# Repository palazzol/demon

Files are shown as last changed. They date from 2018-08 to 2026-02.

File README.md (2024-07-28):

# Demon Debugger system - 2.0 coming soon!

Debugger/Monitor for small "computers"

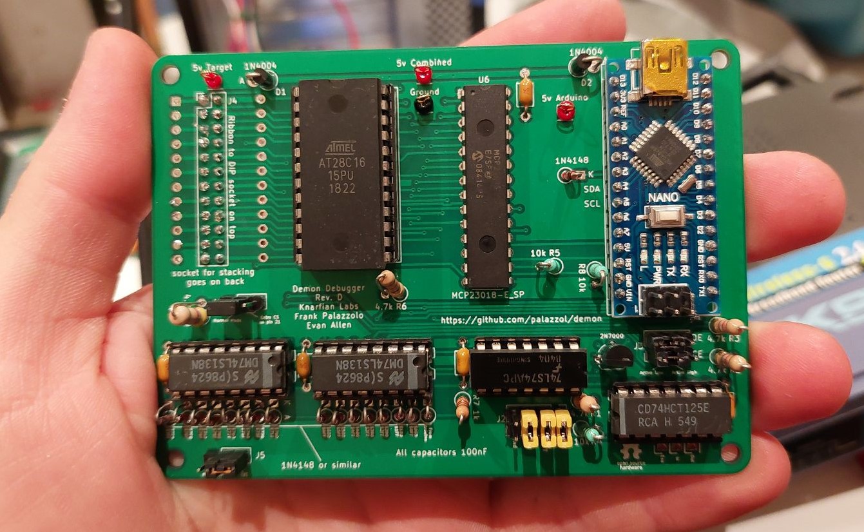
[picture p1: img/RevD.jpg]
RevD Photo


## Vintage Computer Festival Midwest 17 - 2022

- [YouTube](https://youtu.be/M9XML7viIT8)

- [Slides](doc/DD_Presentation-VCFMW_2022.pdf)

## Important Note

**We would like to port this to more systems, and/or help others fix their old things. Please let us know if you need any help getting this system going, should you choose to give it a try!**

## Newly added

* 68HC11 Reference Target - used for Chuck E Cheese Cyberamics computer

## New in version 2.0

* No EPROM programmer needed, reflash through USB serial
* New CPUs supported
  * 6800, 6809
* New targets supported
  * MicroProfessor-1 (Z80 trainer)
  * Heathkit ET-3400(A) (6800 trainer)
  * Heathkit ET-3404 (ET-3400(A) + 6809 adapter) (6809 trainer)
* GUI client
* Python API (alpha) for automating control of targets
* Modularized target code, less work for supporting new targets

## Description

Demon Debugger is a tool that can be used to repair and reverse-engineer devices with 8 and 16 bit CPUs, such as arcade machines, console games, embedded computers, single board computers, etc.  It provides a debugging console, and so is especially useful for systems that lack a working one.

It has been ported to Z80-based, 6502-based, 6800-based, 6809-based, and CP1610-based systems.  There are ports underway to other CPU architectures.

Unfortunately, Demon Debugger can't be used on a totally broken system.  The target system must have a working CPU, and at least a small amount of ROM and RAM.  However, we have found that for most hardware, it's really not too hard to get a system to this point.

## How it Works

In ROM I/O mode, The Demon Debugger board cable plugs into a socket on the target system, in place of a standard JEDEC ROM/EPROM chip.  Then, your PC can communicate with the target over serial, using a standard USB connection.

If your target system is already supported, there will be a target image already built, which you can upload onto your target.  

To support a totally new target system, a small amount of tweaking may need to be done to the assembly code for your target. Generally, if you know the memory map for your system, this is really easy to do.

## More Details

The Demon Debugger system has evolved over time.  If you have a Demon Debugger board, you can use ROM I/O mode with prebuilt target code, and get started right away, without any other tools.  If you need to support a new target, you can still use ROM I/O mode, once you build a new target code.

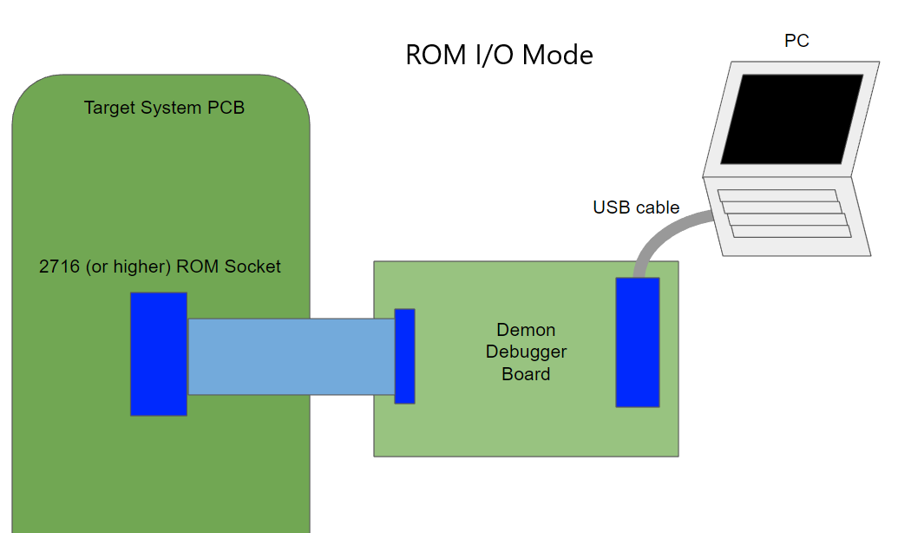
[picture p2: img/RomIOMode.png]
Rom I/O mode diagram


If you don't have a Demon Debugger board, you can still use the Demon Debugger system in Tethered mode, provided you have a few other capabilities.  It requires only an Arduino Nano/Uno, a single transistor, and the ability to program an EPROM chip.  You need to identify points on your target which can be used (2 outputs, 1 input, and a ground), wire up your modified Arduino accordingly, and modify the communication routines in the target to use those points.  There are a few examples in the repo of doing this.

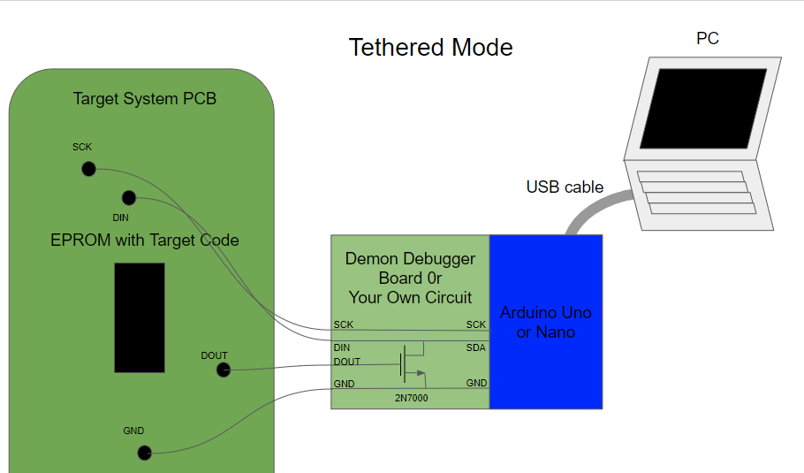
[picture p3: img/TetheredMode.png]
Tethered mode diagram


## Currently Supported Targets

### 6502

* Generic 6502 (Works on most targets) - Atari Asteroids, VCFMW Badge!
* Atari Asteroids Arcade, tethered mode
* Atari Starship 1 Arcade

### 6800

* Heathkit ET-3400(A) (6800 trainer)

### 6809

* Heathkit ET-3404 (ET-3400(A) + 6809 adapter) (6809 trainer)
* Radio Shack Color Computer - Cartridge (6809)

### 6811

* (Chuck E. Cheese Cyberamics Computer) (6811 reference)

### Z80

* Z80 reference code (Tweakable to work on most targets)
* Sega Star Trek Arcade
* Sega Star Trek Arcade, tethered mode
* Bally Midway Gorf Arcade 
* Bally Astrocade, cartridge
* Colecovision/Bit90, cartridge
* Universal Space Raider Arcade
* MicroProfessor-1 (Z80 trainer)

### CP1610

* Mattel Intellivision - via LTO Flash cartridge*

### Other - coming soon

* Mattel Intellivision, via T-Card cartridge (CP1610 target)
* 8080/8085 targets
* Atari 2600 (6502)
* RCA1802 targets
* OS816 SBC (65C816 target)
* TI 99/4A cartridge (TMS9900 target)

## Command Line Client

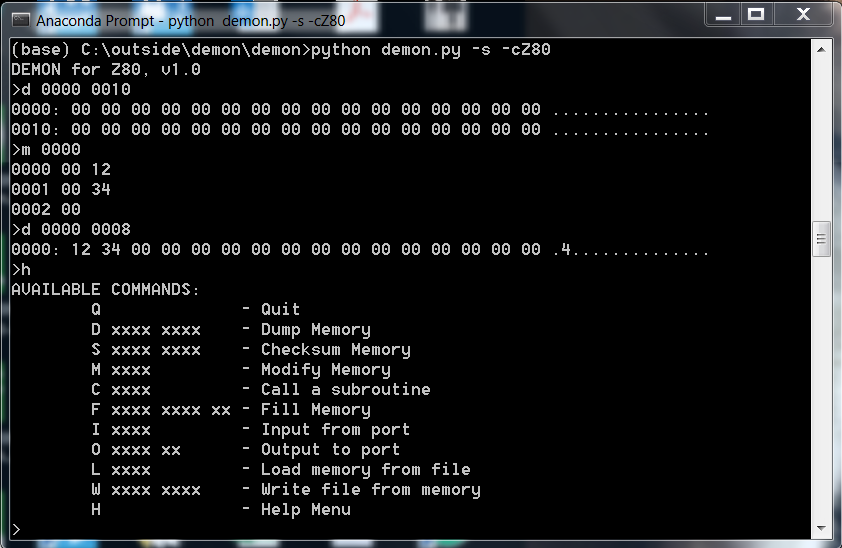
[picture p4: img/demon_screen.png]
Command Line Screenshot


## GUI Client (WIP)

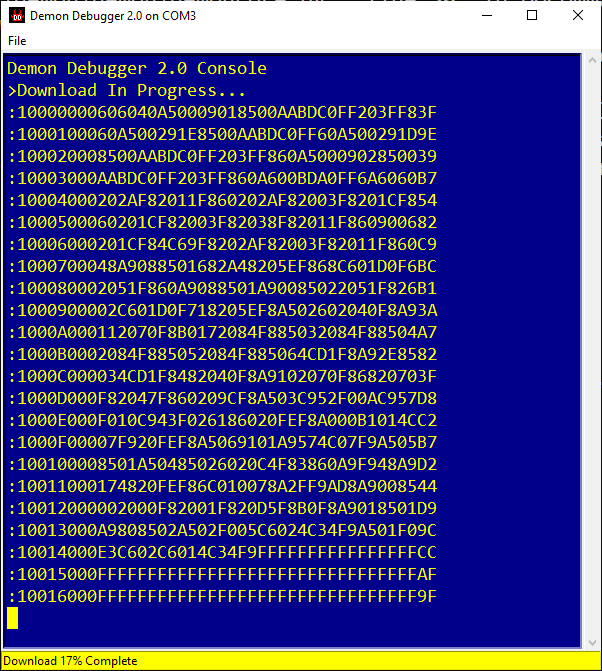
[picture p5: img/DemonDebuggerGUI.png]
GUI Screenshot


## API

For now, please see the file demonapi.py

## Old Videos

Tethered Mode - [Sega Sound Board test](https://www.youtube.com/watch?v=uYlbb8uPjoU) Quality is not very good, but the Arduino module is next to the laptop

[Intellivision Demo](https://www.youtube.com/watch?v=_8YfCMpHLhY) Better quality, no Arduino needed using native serialport on the LTO Flash cart.

## 3D Rendering from KiCad

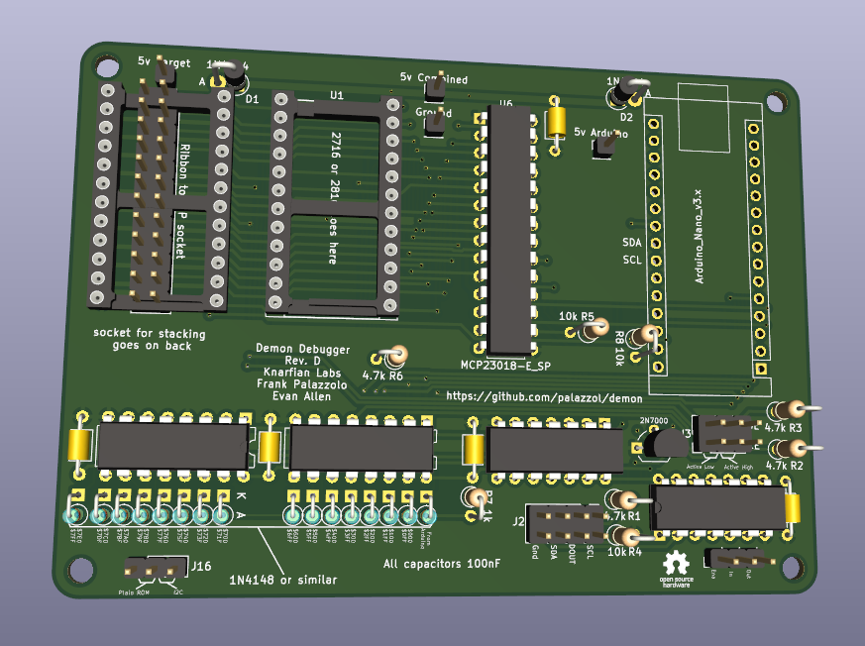
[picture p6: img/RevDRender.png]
Rev D Rendering


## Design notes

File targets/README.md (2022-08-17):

# Building firmware targets for Demon Debugger

Firstly, if you're really lucky, you might find your target code in the bin directory.

If not, head to the src directory

The code is split into subdirectories as follows:

    * core - assembly routines for all CPUs which define the core of Demon Debugger
    * io - assembly routines for interfacing to your target via romio, or tethered mode
    * templates - configuration files (with code snippets) defining how to build a rom image
    * targets - configuration files for each supported target
    * tools - tools needed to build the firmware, but especially ddmake, which does it all

Each target file references a single template file.  This helps a lot, because similar targets share a single template.

For example, if you have a 2K Z80 target (at 0x0000), or a 2K 6502 target (at 0xF800), all the work is done for you.
You will see template files for building either of these, and the z80ref and 6502ref targets use them.

There is also a template for building Z80 cartridge images, which currently works with the Astrocade and Colecovision.

Finally, there are examples of older targets/templates which use the tethered mode of communication.

To build an image, go into the targets directory (where the target .toml files are) and invoke the ddmake.py program with the target (basename) as an argument.  (You will need a python3 environment for now.)  ddmake scans the target and referenced template files, and builds an asm in the corresponding bin/<target>/<target>.asm.  Then, it invokes the assembler, linker, and output converter programs.  If all goes well, you will have:

    * <target>.asm - abbreviated assembly program
    * <target>.bin - binary image
    * <target>.hex - hex file suitable for automatic upload to the Demon Debugger hardware
    * <target>.rst - a nice, absolute listing file of the build image, generated by the linker

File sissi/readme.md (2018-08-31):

# Arduino USB/Serial to Pseudo-I2C Slave Adapter

The Arduino Uno adapter consists of an Arduino Uno,
and a single 2N7000 FET (Transistor)

The target device (cable) has four pins, SCL, DOUT, DIN, and GND
The 2N7000 has three pins, labelled Gate, Drain, and Source
The Arduino itself uses 3 pins, A5 (SCL), A4 (SDA), and GND

The wiring is as follows:

	TARGET      FET         ARDUINO
	--------------------------------
	SCL         N/C         A5 (SCL)
	DOUT        GATE        (N/C)
	DIN         DRAIN       A4 (SDA)
	GND         SOURCE      GND

This arrangement allows the target to provide pure inputs and outputs,
but interface directly to the I2C bus.

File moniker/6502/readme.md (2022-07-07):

## Old build targets
# moniker       - original Asteroids code for use with tethered system
# ref6502_old   - generic 6502 target (Asteroids) - works with Rev C boards
# starship1_old - starship one 6502 target - works with Rev C boards

## New build targets
# ref6502   - generic 6502 target (Asteroids) - works with Rev D boards
# starship1 - Starship One target - - works with Rev D boards

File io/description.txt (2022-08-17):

ROM-based I/O interface for Demon Debugger!

As the type of targets expand beyond Arcade PCBs, it becomes more
difficult to identify I/O pins to use for communication on the target.

Since we are generally replacing code with a EPROM containing the target code,
why not make an interface that looks like part of the EPROM space?

Here is the general idea:

1) Demon Debugger code easily fits into 512 bytes for all targets
2) A 2716-style 2K ROM interface is generic enough to be adapted for most targets
3) Sometimes we need code at the front of memory (ex. Z80 startup, NMI handler, etc.) and
   sometimes the end of memory (ex. 6502 reset vector)
4) So, we use a 2K memory space, but put a "hole" in the middle for I/O

Memory Map for I/O interface:

2K Total Memory Space:

0x000 - 0x79F:  "Front" ROM Space      - pass thru to our EPROM
0x7A0 - 0x7BF:  Special I/O READ area  - D0 reads from the Arduino
0x7C0 - 0x7DF:  Special I/O WRITE area - D1/D0 write to the Arduino
0x7E0 - 0x7ff:  "Back" ROM Space       - pass thru to our EPROM

I/O Reads are easy, skip the EPROM and just read from the Arduino pin

I/O Writes are a little trickier, we fill the EPROM region with D1/D0
matching A1/A0, and then we read from the eprom while writing to the Arduino
with D1/D0 at the same time.  To be clear, the CPU reads from the EPROM, 
but the data on the bus also gets written to the Arduino.

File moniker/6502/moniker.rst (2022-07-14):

                              1 ;
                              2 ; Moniker - 6502 Version
                              3 ; by Frank Palazzolo
                              4 ; For Atari Asteroids
                              5 ;
                              6 ; This code replaces ROM J2 on my Asteroids
                              7 ;
                              8 ; SCL  - WRITE 0x3200, bit0 (0x01) 2 player start lamp - active low only because led is wired to +5V
                              9 ; DOUT - WRITE 0x3200, bit1 (0x02) 1 player start lamp - active low only because led is wired to +5V
                             10 ; DIN  - READ  0x2405, bit7 (0x80) thrust button - inverted on input
                             11 
                             12         .area   CODE1   (ABS)   ; ASXXXX directive, absolute addressing
                             13 
                     2800    14 DIP7	.equ	0x2800	;bit0 = DIP switch 7
                     3200    15 LEDS	.equ	0x3200	;bit0 = 2 player start lamp
                             16 			;bit1 = 1 player start lamp
                             17 		
                     0000    18 LEDBUF	.equ	0x00	;buffer for lamps
                     0001    19 B	.equ	0x01	;general purpose
                     0002    20 C	.equ	0x02	;general purpose
                     0003    21 CMDBUF0 .equ	0x03	;command buffer
                     0004    22 CMDBUF1 .equ	0x04	;command buffer
                     0005    23 CMDBUF2 .equ	0x05	;command buffer
                     0006    24 CMDBUF3 .equ	0x06	;command buffer
                             25 
                     00FE    26 SSTACK	.equ	0xfe	;start of stack
                             27 
                     0011    28 I2CRADR .equ     0x11    ;I2C read address  - I2C address 0x08
                     0010    29 I2CWADR .equ     0x10    ;I2C write address - I2C address 0x08
                             30 
                     0180    31 BIGDEL	.equ	0x0180
                             32 
   7800                      33 	.org	0x7800	;start of rom at j2
                             34 	
   7800 40            [ 6]   35 NMI:	rti
                             36 
   7801 A5 00         [ 3]   37 SETSCL:	lda	LEDBUF
   7803 09 01         [ 2]   38 	ora	#0x01
   7805 85 00         [ 3]   39 	sta	LEDBUF
   7807 8D 00 32      [ 4]   40 	sta	LEDS
   780A 20 37 78      [ 6]   41 	jsr	I2CDLY
   780D 60            [ 6]   42 	rts
                             43 
   780E A5 00         [ 3]   44 CLRSCL:	lda	LEDBUF
   7810 29 FE         [ 2]   45 	and	#0xfe
   7812 85 00         [ 3]   46 	sta	LEDBUF
   7814 8D 00 32      [ 4]   47 	sta	LEDS
   7817 60            [ 6]   48 	rts
                             49 	
   7818 A5 00         [ 3]   50 SETSDA:	lda	LEDBUF
   781A 29 FD         [ 2]   51 	and	#0xfd
   781C 85 00         [ 3]   52 	sta	LEDBUF
   781E 8D 00 32      [ 4]   53 	sta	LEDS
   7821 20 37 78      [ 6]   54 	jsr	I2CDLY
   7824 60            [ 6]   55 	rts
                             56 
   7825 A5 00         [ 3]   57 CLRSDA:	lda	LEDBUF
   7827 09 02         [ 2]   58 	ora	#0x02
   7829 85 00         [ 3]   59 	sta	LEDBUF
   782B 8D 00 32      [ 4]   60 	sta	LEDS
   782E 20 37 78      [ 6]   61 	jsr	I2CDLY
   7831 60            [ 6]   62 	rts
                             63 
   7832                      64 READSDA:        
   7832 AD 00 28      [ 4]   65         lda	DIP7
   7835 6A            [ 2]   66 	ror			
   7836 60            [ 6]   67 	rts				
                             68 
                             69 ; Delay for half a bit time
   7837 60            [ 6]   70 I2CDLY:	rts		; TBD - this is plenty?
                             71 
                             72 ; I2C Start Condition
   7838                      73 I2CSTART:
   7838 20 25 78      [ 6]   74         jsr    CLRSDA      
   783B 20 0E 78      [ 6]   75         jsr    CLRSCL
   783E 60            [ 6]   76         rts
                             77 
                             78 ; I2C Stop Condition
                             79 ; Uses HL
                             80 ; Destroys A
   783F                      81 I2CSTOP:
   783F 20 25 78      [ 6]   82         jsr    CLRSDA
   7842 20 01 78      [ 6]   83         jsr    SETSCL
   7845 20 18 78      [ 6]   84         jsr    SETSDA
   7848 60            [ 6]   85         rts
                             86         
   7849                      87 I2CRBIT:
   7849 20 18 78      [ 6]   88 	jsr	SETSDA
   784C 20 01 78      [ 6]   89 	jsr	SETSCL
   784F 20 32 78      [ 6]   90 	jsr	READSDA	; sets/clears carry flag
   7852 20 0E 78      [ 6]   91 	jsr     CLRSCL
   7855 60            [ 6]   92 	rts		; carry flag still good here
                             93 
   7856                      94 I2CWBIT:
   7856 90 06         [ 4]   95 	bcc	DOCLR
   7858 20 18 78      [ 6]   96 	jsr	SETSDA
   785B 4C 61 78      [ 3]   97 	jmp	AHEAD
   785E                      98 DOCLR:
   785E 20 25 78      [ 6]   99 	jsr	CLRSDA
   7861                     100 AHEAD:
   7861 20 01 78      [ 6]  101 	jsr	SETSCL
   7864 20 0E 78      [ 6]  102 	jsr	CLRSCL
   7867 60            [ 6]  103 	rts
                            104         
   7868                     105 I2CWBYTE:
   7868 48            [ 3]  106 	pha
   7869 A9 08         [ 2]  107 	lda	#0x08
   786B 85 01         [ 3]  108 	sta	B
   786D 68            [ 4]  109 	pla
   786E                     110 ILOOP:
   786E 2A            [ 2]  111 	rol
   786F 48            [ 3]  112 	pha
   7870 20 56 78      [ 6]  113 	jsr	I2CWBIT
   7873 68            [ 4]  114 	pla
   7874 C6 01         [ 5]  115 	dec	B
   7876 D0 F6         [ 4]  116 	bne	ILOOP
   7878 20 49 78      [ 6]  117 	jsr	I2CRBIT
   787B 60            [ 6]  118 	rts
                            119 	
   787C                     120 I2CRBYTE:
   787C A9 08         [ 2]  121         lda	#0x08
   787E 85 01         [ 3]  122 	sta	B
   7880 A9 00         [ 2]  123 	lda	#0x00
   7882 85 02         [ 3]  124 	sta	C
   7884                     125 LOOP3:
   7884 20 49 78      [ 6]  126         jsr     I2CRBIT     ; get bit in carry flag
   7887 26 02         [ 5]  127         rol     C           ; rotate carry into bit0 of C register
   7889 C6 01         [ 5]  128         dec	B
   788B D0 F7         [ 4]  129         bne    	LOOP3
   788D 18            [ 2]  130         clc           	    ; clear carry flag              
   788E 20 56 78      [ 6]  131         jsr   	I2CWBIT
   7891 A5 02         [ 3]  132         lda  	C
   7893 60            [ 6]  133         rts
                            134 
   7894                     135 I2CRREQ:
   7894 20 38 78      [ 6]  136         jsr     I2CSTART
   7897 A9 11         [ 2]  137         lda	#I2CRADR
   7899 20 68 78      [ 6]  138         jsr     I2CWBYTE
   789C B0 17         [ 4]  139         bcs     SKIP
   789E 20 7C 78      [ 6]  140         jsr     I2CRBYTE
   78A1 85 03         [ 3]  141         sta     CMDBUF0
   78A3 20 7C 78      [ 6]  142         jsr     I2CRBYTE
   78A6 85 04         [ 3]  143         sta     CMDBUF1
   78A8 20 7C 78      [ 6]  144         jsr     I2CRBYTE
   78AB 85 05         [ 3]  145         sta     CMDBUF2
   78AD 20 7C 78      [ 6]  146         jsr     I2CRBYTE
   78B0 85 06         [ 3]  147         sta     CMDBUF3
   78B2 4C C9 78      [ 3]  148         jmp     ENDI2C
                            149     
   78B5                     150 SKIP:                       ; If no device present, fake an idle response
   78B5 A9 2E         [ 2]  151         lda     #0x2e  ; '.'
   78B7 85 03         [ 3]  152         sta     CMDBUF0
   78B9 4C C9 78      [ 3]  153         jmp     ENDI2C
                            154 
   78BC                     155 I2CSRESP:
   78BC 48            [ 3]  156         pha
   78BD 20 38 78      [ 6]  157         jsr     I2CSTART
   78C0 A9 10         [ 2]  158         lda     #I2CWADR
   78C2 20 68 78      [ 6]  159         jsr     I2CWBYTE
   78C5 68            [ 4]  160         pla
   78C6 20 68 78      [ 6]  161         jsr     I2CWBYTE
   78C9                     162 ENDI2C:
   78C9 20 3F 78      [ 6]  163         jsr     I2CSTOP
   78CC 60            [ 6]  164         rts
                            165 
   78CD                     166 POLL:
   78CD 20 94 78      [ 6]  167         jsr     I2CRREQ
   78D0 A5 03         [ 3]  168         lda     CMDBUF0
   78D2 C9 52         [ 2]  169         cmp     #0x52    	; 'R' - Read memory
   78D4 F0 0A         [ 4]  170         beq     MREAD
   78D6 C9 57         [ 2]  171         cmp     #0x57    	; 'W' - Write memory
   78D8 F0 10         [ 4]  172         beq	MWRITE
   78DA C9 43         [ 2]  173         cmp     #0x43    	; 'C' - Call subroutine
   78DC F0 26         [ 4]  174         beq	REMCALL
   78DE 18            [ 2]  175         clc
   78DF 60            [ 6]  176         rts
                            177 
   78E0                     178 MREAD:
   78E0 20 F6 78      [ 6]  179         jsr     LOADBC
   78E3 A0 00         [ 2]  180         ldy	#0x00
   78E5 B1 01         [ 6]  181         lda	[B],Y
   78E7 4C FF 78      [ 3]  182         jmp     SRESP
   78EA                     183 MWRITE:
   78EA 20 F6 78      [ 6]  184         jsr     LOADBC
   78ED A5 06         [ 3]  185         lda     CMDBUF3
   78EF 91 01         [ 6]  186         sta     [B],Y
   78F1 A9 57         [ 2]  187         lda     #0x57  	;'W'
   78F3 4C FF 78      [ 3]  188         jmp     SRESP
   78F6                     189 LOADBC:
   78F6 A5 05         [ 3]  190 	lda	CMDBUF2
   78F8 85 01         [ 3]  191 	sta	B
   78FA A5 04         [ 3]  192 	lda	CMDBUF1
   78FC 85 02         [ 3]  193 	sta	C
   78FE 60            [ 6]  194 	rts
                            195 	
   78FF                     196 SRESP:
   78FF 20 BC 78      [ 6]  197         jsr    I2CSRESP
   7902                     198 RHERE:
   7902 38            [ 2]  199         sec
   7903 60            [ 6]  200         rts
   7904                     201 REMCALL:
   7904 A9 79         [ 2]  202 	lda	#>(START-1)
   7906 48            [ 3]  203         pha
   7907 A9 0F         [ 2]  204 	lda	#<(START-1)
   7909 48            [ 3]  205         pha
   790A 20 F6 78      [ 6]  206         jsr     LOADBC
   790D 6C 01 00      [ 5]  207         jmp     [B]
                            208         
                            209 ;;;;;;;;;;
                            210 	
   7910                     211 START:	
   7910 A2 FE         [ 2]  212 	ldx	#SSTACK
   7912 9A            [ 2]  213 	txs		; Init stack
   7913 D8            [ 2]  214 	cld		; No Decimal
                            215 
                            216 ; Main routine
   7914                     217 MAIN:
   7914 20 CD 78      [ 6]  218         jsr     POLL
   7917 B0 FB         [ 4]  219         bcs     MAIN
                            220         
   7919 A9 01         [ 2]  221         lda	#BIGDEL>>8
   791B 85 01         [ 3]  222         sta	B
   791D A9 80         [ 2]  223         lda	#BIGDEL%256
   791F 85 02         [ 3]  224         sta	C
   7921                     225 MLOOP:
   7921 A5 02         [ 3]  226         lda	C
   7923 F0 05         [ 4]  227         beq	DECBOTH
   7925 C6 02         [ 5]  228         dec	C
   7927 4C 21 79      [ 3]  229         jmp	MLOOP
   792A                     230 DECBOTH:
   792A A5 01         [ 3]  231 	lda	B
   792C F0 E6         [ 4]  232 	beq	MAIN
   792E C6 02         [ 5]  233 	dec	C
   7930 C6 01         [ 5]  234 	dec	B
   7932 4C 21 79      [ 3]  235 	jmp	MLOOP
                            236 
   7FFA                     237 	.org	0x7ffa
   7FFA 00 78               238 	.dw	NMI
   7FFC 10 79               239 	.dw	START
   7FFE 10 79               240 	.dw	START
                            241 	
                            242 	
                            243

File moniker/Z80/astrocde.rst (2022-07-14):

                              1 ;
                              2 ; Moniker - Z80 Version, 2716 version in Bally Astrocade cartridge
                              3 ; by Frank Palazzolo
                              4 ;
                              5 ; "2716" Memory Map
                              6 ; X000-X3FF - ROM
                              7 ; X400-X5FF - I/O (Special region)
                              8 ; X600-X7FF - ROM
                              9 
                             10 ; SCL connected to A0
                             11 ; DOUT connected to A1
                             12 ; DIN connected to D0
                             13 
                             14 ; "Special Region"
                             15 ; Read from X4X0 - clear SCL, clear DOUT
                             16 ; Read from X4X1 -   set SCL, clear DOUT
                             17 ; Read from X4X2 - clear SCL,   set DOUT
                             18 ; Read from X4X3 -   set SCL,   set DOUT
                             19 ; All reads return DIN as bit 0
                             20 
                             21         .area   CODE1   (ABS)   ; ASXXXX directive, absolute addressing
                             22 
                             23 ;DSPORT  .equ    0x13        ; dip switch 1 port
                             24 ;CCPORT  .equ    0x16        ; port for lamps
                             25 
                     4FCE    26 CMDBUF  .equ    0x4fce      ; Need only 4 bytes of ram for command buffer
                             27                             ; (We will save 12 more just in case)
                             28 ;SSTACK  .equ    0xdff0      ; Start of stack
                             29 
                     0011    30 I2CRADR .equ    0x11        ; I2C read address  - I2C address 0x08
                     0010    31 I2CWADR .equ    0x10        ; I2C write address - I2C address 0x08
                             32 
                     0180    33 BIGDEL  .equ    0x0180      ; bigger delay, for now still fairly small
                             34 
   2000                      35         .org    0x2000	    ; cartridge start
                             36         
   2000 55                   37         .byte   0x55	    ; cartridge header
   2001 18 02                38         .word   0x0218	    ; next menu item (first one)
   2003 19 20                39         .word   TITLE	    ; title pointer
   2005 5B 21                40         .word   START	    ; start pointer
                             41         
   2007 C9            [10]   42         ret		    ; rst8
   2008 00            [ 4]   43         nop
   2009 00            [ 4]   44         nop
                             45 
   200A C9            [10]   46         ret		    ; rst16
   200B 00            [ 4]   47         nop
   200C 00            [ 4]   48         nop
                             49         
   200D C9            [10]   50 	ret		    ; rst24
   200E 00            [ 4]   51 	nop
   200F 00            [ 4]   52         nop
                             53         
   2010 C9            [10]   54 	ret		    ; rst32
   2011 00            [ 4]   55 	nop
   2012 00            [ 4]   56         nop
                             57         
   2013 C9            [10]   58 	ret		    ; rst40
   2014 00            [ 4]   59 	nop
   2015 00            [ 4]   60         nop
                             61         
   2016 C9            [10]   62 	ret		    ; rst48
   2017 00            [ 4]   63 	nop
   2018 00            [ 4]   64         nop
                             65         
   2019 44 45 4D 4F 4E 20    66 TITLE:	.ascii	"DEMON DEBUGGER"
        44 45 42 55 47 47
        45 52
   2027 00                   67 	.byte	0x00
                             68 
                             69 ; Set the SCL pin high
                             70 ; D is the global buffer
                             71 ; Destroys A
   2028                      72 SETSCL:
   2028 7A            [ 4]   73         LD      A,D
   2029 F6 01         [ 7]   74         OR      0x01
   202B 57            [ 4]   75         LD      D,A
   202C E5            [11]   76         PUSH    HL
   202D 26 24         [ 7]   77         LD      H,0x24
   202F 6F            [ 4]   78         LD      L,A
   2030 7E            [ 7]   79         LD      A,(HL)
   2031 E1            [10]   80         POP     HL
   2032 CD 6A 20      [17]   81         CALL    I2CDELAY
   2035 C9            [10]   82         RET
                             83     
                             84 ; Set the SCL pin low
                             85 ; D is the global buffer
                             86 ; Destroys A
   2036                      87 CLRSCL:
   2036 7A            [ 4]   88         LD      A,D
   2037 E6 FE         [ 7]   89         AND     0xfe
   2039 57            [ 4]   90         LD      D,A
   203A E5            [11]   91         PUSH    HL
   203B 26 24         [ 7]   92         LD      H,0x24
   203D 6F            [ 4]   93         LD      L,A
   203E 7E            [ 7]   94         LD      A,(HL)
   203F E1            [10]   95         POP     HL
   2040 CD 6A 20      [17]   96         CALL    I2CDELAY
   2043 C9            [10]   97         RET
                             98 
                             99 ; Set the DOUT pin low
                            100 ; D is the global buffer
                            101 ; Destroys A 
   2044                     102 SETSDA:
   2044 7A            [ 4]  103         LD      A,D
   2045 E6 FD         [ 7]  104         AND     0xfd
   2047 57            [ 4]  105         LD      D,A
   2048 E5            [11]  106         PUSH    HL
   2049 26 24         [ 7]  107         LD      H,0x24
   204B 6F            [ 4]  108         LD      L,A
   204C 7E            [ 7]  109         LD      A,(HL)
   204D E1            [10]  110         POP     HL
   204E CD 6A 20      [17]  111         CALL    I2CDELAY
   2051 C9            [10]  112         RET
                            113 
                            114 ; Set the DOUT pin high
                            115 ; D is the global buffer
                            116 ; Destroys A  
   2052                     117 CLRSDA:
   2052 7A            [ 4]  118         LD      A,D
   2053 F6 02         [ 7]  119         OR      0x02
   2055 57            [ 4]  120         LD      D,A
   2056 E5            [11]  121         PUSH    HL
   2057 26 24         [ 7]  122         LD      H,0x24
   2059 6F            [ 4]  123         LD      L,A
   205A 7E            [ 7]  124         LD      A,(HL)
   205B E1            [10]  125         POP     HL
   205C CD 6A 20      [17]  126         CALL    I2CDELAY
   205F C9            [10]  127         RET
                            128 
                            129 ; Read the DIN pin 
                            130 ; returns bit in carry flag    
   2060                     131 READSDA:
   2060 7A            [ 4]  132         LD      A,D
   2061 E5            [11]  133         PUSH    HL
   2062 26 24         [ 7]  134         LD      H,0x24
   2064 6F            [ 4]  135         LD      L,A
   2065 7E            [ 7]  136         LD      A,(HL)
   2066 E1            [10]  137         POP     HL
   2067 CB 3F         [ 8]  138         SRL     A           ;carry flag
   2069 C9            [10]  139         RET
                            140     
                            141 ; Delay for half a bit time
   206A                     142 I2CDELAY:
   206A C9            [10]  143         RET     ; This is plenty
                            144 
                            145 ; I2C Start Condition
                            146 ; Uses HL
                            147 ; Destroys A
   206B                     148 I2CSTART:
   206B CD 52 20      [17]  149         CALL    CLRSDA      
   206E CD 36 20      [17]  150         CALL    CLRSCL
   2071 C9            [10]  151         RET
                            152 
                            153 ; I2C Stop Condition
                            154 ; Uses HL
                            155 ; Destroys A
   2072                     156 I2CSTOP:
   2072 CD 52 20      [17]  157         CALL    CLRSDA
   2075 CD 28 20      [17]  158         CALL    SETSCL
   2078 CD 44 20      [17]  159         CALL    SETSDA
   207B C9            [10]  160         RET
                            161 
                            162 ; I2C Read Bit routine
                            163 ; Returns bit in carry blag
                            164 ; Destroys A
   207C                     165 I2CRBIT:
   207C CD 44 20      [17]  166         CALL    SETSDA
   207F CD 28 20      [17]  167         CALL    SETSCL
   2082 CD 60 20      [17]  168         CALL    READSDA
   2085 F5            [11]  169         PUSH    AF          ; save carry flag
   2086 CD 36 20      [17]  170         CALL    CLRSCL
   2089 F1            [10]  171         POP     AF          ; rv in carry flag
   208A C9            [10]  172         RET
                            173 
                            174 ; I2C Write Bit routine
                            175 ; Takes carry flag
                            176 ; Destroys A
   208B                     177 I2CWBIT:
   208B 30 05         [12]  178         JR      NC,DOCLR
   208D CD 44 20      [17]  179         CALL    SETSDA
   2090 18 03         [12]  180         JR      AHEAD
   2092                     181 DOCLR:
   2092 CD 52 20      [17]  182         CALL    CLRSDA
   2095                     183 AHEAD:
   2095 CD 28 20      [17]  184         CALL    SETSCL
   2098 CD 36 20      [17]  185         CALL    CLRSCL
   209B C9            [10]  186         RET
                            187         
                            188 ; I2C Write Byte routine
                            189 ; Takes A
                            190 ; Destroys B
                            191 ; Returns carry bit
   209C                     192 I2CWBYTE:
   209C 06 08         [ 7]  193         LD      B,8
   209E                     194 ILOOP:
   209E C5            [11]  195         PUSH    BC          ; save B
   209F CB 07         [ 8]  196         RLC     A    
   20A1 F5            [11]  197         PUSH    AF          ; save A
   20A2 CD 8B 20      [17]  198         CALL    I2CWBIT
   20A5 F1            [10]  199         POP     AF
   20A6 C1            [10]  200         POP     BC
   20A7 10 F5         [13]  201         DJNZ    ILOOP
   20A9 CD 7C 20      [17]  202         CALL    I2CRBIT
   20AC C9            [10]  203         RET
                            204 
                            205 ; I2C Read Byte routine
                            206 ; Destroys BC
                            207 ; Returns A
   20AD                     208 I2CRBYTE:
   20AD 06 08         [ 7]  209         LD      B,8
   20AF 0E 00         [ 7]  210         LD      C,0
   20B1                     211 LOOP3:
   20B1 C5            [11]  212         PUSH    BC
   20B2 CD 7C 20      [17]  213         CALL    I2CRBIT     ; get bit in carry flag
   20B5 C1            [10]  214         POP     BC
   20B6 CB 11         [ 8]  215         RL      C           ; rotate carry into bit0 of C register
   20B8 10 F7         [13]  216         DJNZ    LOOP3
   20BA AF            [ 4]  217         XOR     A           ; clear carry flag              
   20BB C5            [11]  218         PUSH    BC
   20BC CD 8B 20      [17]  219         CALL    I2CWBIT
   20BF C1            [10]  220         POP     BC
   20C0 79            [ 4]  221         LD      A,C
   20C1 C9            [10]  222         RET
                            223 ;
                            224 
                            225 ; Read 4-byte I2C Command from device into CMDBUF
                            226 ; Uses HL
                            227 ; Destroys A,BC,HL
   20C2                     228 I2CRREQ:
   20C2 CD 6B 20      [17]  229         CALL    I2CSTART
   20C5 3E 11         [ 7]  230         LD      A,I2CRADR
   20C7 CD 9C 20      [17]  231         CALL    I2CWBYTE
   20CA 38 1A         [12]  232         JR      C,SKIP
   20CC CD AD 20      [17]  233         CALL    I2CRBYTE
   20CF DD 77 00      [19]  234         LD      (IX),A
   20D2 CD AD 20      [17]  235         CALL    I2CRBYTE
   20D5 DD 77 01      [19]  236         LD      (IX+1),A  
   20D8 CD AD 20      [17]  237         CALL    I2CRBYTE
   20DB DD 77 02      [19]  238         LD      (IX+2),A
   20DE CD AD 20      [17]  239         CALL    I2CRBYTE
   20E1 DD 77 03      [19]  240         LD      (IX+3),A
   20E4 18 14         [12]  241         JR      ENDI2C
                            242     
   20E6                     243 SKIP:                       ; If no device present, fake an idle response
   20E6 3E 2E         [ 7]  244         LD      A,0x2e  ; '.'
   20E8 DD 77 00      [19]  245         LD      (IX),A
   20EB 18 0D         [12]  246         JR      ENDI2C
                            247 
   20ED                     248 I2CSRESP:
   20ED F5            [11]  249         PUSH    AF
   20EE CD 6B 20      [17]  250         CALL    I2CSTART
   20F1 3E 10         [ 7]  251         LD      A,I2CWADR
   20F3 CD 9C 20      [17]  252         CALL    I2CWBYTE
   20F6 F1            [10]  253         POP     AF
   20F7 CD 9C 20      [17]  254         CALL    I2CWBYTE
   20FA                     255 ENDI2C:
   20FA CD 72 20      [17]  256         CALL    I2CSTOP
   20FD C9            [10]  257         RET
                            258 ;
                            259 
                            260 ; Main Polling loop
                            261 ; Return carry flag if we got a valid command (not idle)
   20FE                     262 POLL:
   20FE CD C2 20      [17]  263         CALL    I2CRREQ
   2101 DD 7E 00      [19]  264         LD      A,(IX)
   2104 FE 52         [ 7]  265         CP      0x52    ; 'R' - Read memory
   2106 28 1B         [12]  266         JR      Z,MREAD
   2108 FE 57         [ 7]  267         CP      0x57    ; 'W' - Write memory
   210A 28 1D         [12]  268         JR      Z,MWRITE
   210C FE 49         [ 7]  269         CP      0x49    ; 'I' - Input from port
   210E 28 2D         [12]  270         JR      Z,PREAD
   2110 FE 4F         [ 7]  271         CP      0x4F    ; 'O' - Output from port
   2112 28 30         [12]  272         JR      Z,PWRITE
   2114 FE 43         [ 7]  273         CP      0x43    ; 'C' - Call subroutine
   2116 28 3B         [12]  274         JR      Z,REMCALL
   2118 3F            [ 4]  275         CCF
   2119 C9            [10]  276         RET
   211A                     277 LOADHL:
   211A DD 7E 01      [19]  278         LD      A,(IX+1)
   211D 67            [ 4]  279         LD      H,A
   211E DD 7E 02      [19]  280         LD      A,(IX+2)
   2121 6F            [ 4]  281         LD      L,A
   2122 C9            [10]  282         RET    
   2123                     283 MREAD:
   2123 CD 34 21      [17]  284         CALL    LOADBC
   2126 0A            [ 7]  285         LD      A,(BC)
   2127 18 25         [12]  286         JR      SRESP
   2129                     287 MWRITE:
   2129 CD 34 21      [17]  288         CALL    LOADBC
   212C DD 7E 03      [19]  289         LD      A,(IX+3)
   212F 02            [ 7]  290         LD      (BC),A
   2130 3E 57         [ 7]  291         LD      A,0x57  ;'W'
   2132 18 1A         [12]  292         JR      SRESP
   2134                     293 LOADBC:
   2134 DD 7E 01      [19]  294         LD      A,(IX+1)
   2137 47            [ 4]  295         LD      B,A
   2138 DD 7E 02      [19]  296         LD      A,(IX+2)
   213B 4F            [ 4]  297         LD      C,A
   213C C9            [10]  298         RET
   213D                     299 PREAD:
   213D CD 34 21      [17]  300         CALL    LOADBC
   2140 ED 78         [12]  301         IN      A,(C)
   2142 18 0A         [12]  302         JR      SRESP
   2144                     303 PWRITE:
   2144 CD 34 21      [17]  304         CALL    LOADBC
   2147 DD 7E 03      [19]  305         LD      A,(IX+3)
   214A ED 79         [12]  306         OUT     (C),A
   214C 3E 4F         [ 7]  307         LD      A,0x4F  ;'O'
   214E                     308 SRESP:
   214E CD ED 20      [17]  309         CALL    I2CSRESP
   2151                     310 RHERE:
   2151 37            [ 4]  311         SCF
   2152 C9            [10]  312         RET
   2153                     313 REMCALL:
   2153 21 5B 21      [10]  314         LD      HL,START
   2156 E5            [11]  315         PUSH    HL
   2157 CD 1A 21      [17]  316         CALL    LOADHL
   215A E9            [ 4]  317         JP      (HL)
                            318     
   215B                     319 START:
                            320 	;DI
                            321         ;LD      SP,SSTACK   ; have to set valid SP
   215B DD 21 CE 4F   [14]  322         LD      IX,CMDBUF   ; Easy to index command buffer
                            323         
                            324 ; Main routine
   215F                     325 MAIN:
   215F DB 10         [11]  326 	IN	A,(0x10)    ; hit watchdog
   2161 CD FE 20      [17]  327         CALL    POLL
   2164 38 F9         [12]  328         JR      C,MAIN
                            329         
   2166 01 80 01      [10]  330         LD      BC,BIGDEL
   2169                     331 MLOOP:
   2169 0B            [ 6]  332         DEC     BC
   216A 79            [ 4]  333         LD      A,C
   216B B0            [ 4]  334         OR      B
   216C 20 FB         [12]  335         JR      NZ,MLOOP
   216E 18 EF         [12]  336         JR      MAIN
                            337 
                            338 
                            339     
                            340

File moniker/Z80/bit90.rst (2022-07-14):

                              1 ;
                              2 ; Moniker - Z80 Version
                              3 ; by Frank Palazzolo
                              4 ; For Bit90 by Bit Corporation
                              5 ;
                              6         .area   CODE1   (ABS)   ; ASXXXX directive, absolute addressing
                              7 
                     A000     8 DATAIN	.equ	0xa000		; where to read data in from
                              9 
                     77F0    10 CMDBUF  .equ    0x77f0      ; Need only 4 bytes of ram for command buffer
                             11                             ; (We will save 12 more just in case)
                     77FF    12 OUTBUF  .equ    0x77ff
                     77F0    13 SSTACK  .equ    0x77f0      ; Start of stack
                             14 
                     0011    15 I2CRADR .equ    0x11        ; I2C read address  - I2C address 0x08
                     0010    16 I2CWADR .equ    0x10        ; I2C write address - I2C address 0x08
                             17 
                     0180    18 BIGDEL  .equ    0x0180      ; bigger delay, for now still fairly small
                             19 
   8000                      20         .org    0x8000	    ; cartridge start
                             21     		
   8000 AA                   22     	.db	0xaa	    ; cartridge signature
   8001 55                   23     	.db	0x55
                             24     	
   8002 00 00                25     	.dw     0x0000
   8004 00 00                26     	.dw     0x0000
   8006 00 00                27     	.dw     0x0000
   8008 00 00                28     	.dw     0x0000
   800A 46 80                29     	.dw     START
   800C C3 08 00      [10]   30     	JP      0x0008
   800F C3 10 00      [10]   31     	JP      0x0010
   8012 C3 18 00      [10]   32     	JP      0x0018
   8015 C3 20 00      [10]   33     	JP      0x0020
   8018 C3 28 00      [10]   34     	JP      0x0028
   801B C3 30 00      [10]   35     	JP      0x0030
   801E C3 38 00      [10]   36     	JP      0x0038
   8021 C3 66 00      [10]   37     	JP      0x0066
                             38     	
   8024 42 59 3A 20 45 56    39     	.ascii  "BY: EVAN&FRANK/DEMON DEBUGGER/2019"
        41 4E 26 46 52 41
        4E 4B 2F 44 45 4D
        4F 4E 20 44 45 42
        55 47 47 45 52 2F
        32 30 31 39
                             40     	
   8046 F3            [ 4]   41 START:  DI                  ; Disable interrupts - we don't handle them
   8047 C3 7A 81      [10]   42         JP      INIT        ; go to initialization code
                             43     
                             44 ; Set the SCL pin high
                             45 ; D is the global buffer
                             46 ; Destroys A
   804A                      47 SETSCL:
   804A 7A            [ 4]   48         LD      A,D
   804B F6 01         [ 7]   49         OR      0x01
   804D 57            [ 4]   50         LD      D,A
   804E E5            [11]   51         PUSH    HL
   804F 26 C0         [ 7]   52         LD      H,0xc0
   8051 6F            [ 4]   53         LD      L,A
   8052 7E            [ 7]   54         LD      A,(HL)
   8053 E1            [10]   55         POP     HL
   8054 CD 89 80      [17]   56         CALL    I2CDELAY
   8057 C9            [10]   57         RET
                             58     
                             59 ; Set the SCL pin low
                             60 ; D is the global buffer
                             61 ; Destroys A
   8058                      62 CLRSCL:
   8058 7A            [ 4]   63         LD      A,D
   8059 E6 FE         [ 7]   64         AND     0xfe
   805B 57            [ 4]   65         LD      D,A
   805C E5            [11]   66         PUSH    HL
   805D 26 C0         [ 7]   67         LD      H,0xc0
   805F 6F            [ 4]   68         LD      L,A
   8060 7E            [ 7]   69         LD      A,(HL)
   8061 E1            [10]   70         POP     HL
   8062 CD 89 80      [17]   71         CALL    I2CDELAY
   8065 C9            [10]   72         RET
                             73 
                             74 ; Set the DOUT pin low
                             75 ; D is the global buffer
                             76 ; Destroys A 
   8066                      77 SETSDA:
   8066 7A            [ 4]   78         LD      A,D
   8067 E6 FD         [ 7]   79         AND     0xfd
   8069 57            [ 4]   80         LD      D,A
   806A E5            [11]   81         PUSH    HL
   806B 26 C0         [ 7]   82         LD      H,0xc0
   806D 6F            [ 4]   83         LD      L,A
   806E 7E            [ 7]   84         LD      A,(HL)
   806F E1            [10]   85         POP     HL
   8070 CD 89 80      [17]   86         CALL    I2CDELAY
   8073 C9            [10]   87         RET
                             88 
                             89 ; Set the DOUT pin high
                             90 ; D is the global buffer
                             91 ; Destroys A  
   8074                      92 CLRSDA:
   8074 7A            [ 4]   93         LD      A,D
   8075 F6 02         [ 7]   94         OR      0x02
   8077 57            [ 4]   95         LD      D,A
   8078 E5            [11]   96         PUSH    HL
   8079 26 C0         [ 7]   97         LD      H,0xc0
   807B 6F            [ 4]   98         LD      L,A
   807C 7E            [ 7]   99         LD      A,(HL)
   807D E1            [10]  100         POP     HL
   807E CD 89 80      [17]  101         CALL    I2CDELAY
   8081 C9            [10]  102         RET
                            103 
                            104 ; Read the DIN pin 
                            105 ; returns bit in carry flag    
   8082                     106 READSDA:
   8082 21 00 A0      [10]  107         LD      HL,DATAIN
   8085 7E            [ 7]  108         LD      A,(HL)      ;perform a read into bit0
   8086 CB 3F         [ 8]  109         SRL     A           ;carry flag
   8088 C9            [10]  110         RET
                            111     
                            112 ; Delay for half a bit time
   8089                     113 I2CDELAY:
   8089 C9            [10]  114         RET     ; This is plenty
                            115 
                            116 ; I2C Start Condition
                            117 ; Uses HL
                            118 ; Destroys A
   808A                     119 I2CSTART:
   808A CD 74 80      [17]  120         CALL    CLRSDA      
   808D CD 58 80      [17]  121         CALL    CLRSCL
   8090 C9            [10]  122         RET
                            123 
                            124 ; I2C Stop Condition
                            125 ; Uses HL
                            126 ; Destroys A
   8091                     127 I2CSTOP:
   8091 CD 74 80      [17]  128         CALL    CLRSDA
   8094 CD 4A 80      [17]  129         CALL    SETSCL
   8097 CD 66 80      [17]  130         CALL    SETSDA
   809A C9            [10]  131         RET
                            132 
                            133 ; I2C Read Bit routine
                            134 ; Returns bit in carry blag
                            135 ; Destroys A
   809B                     136 I2CRBIT:
   809B CD 66 80      [17]  137         CALL    SETSDA
   809E CD 4A 80      [17]  138         CALL    SETSCL
   80A1 CD 82 80      [17]  139         CALL    READSDA
   80A4 F5            [11]  140         PUSH    AF          ; save carry flag
   80A5 CD 58 80      [17]  141         CALL    CLRSCL
   80A8 F1            [10]  142         POP     AF          ; rv in carry flag
   80A9 C9            [10]  143         RET
                            144 
                            145 ; I2C Write Bit routine
                            146 ; Takes carry flag
                            147 ; Destroys A
   80AA                     148 I2CWBIT:
   80AA 30 05         [12]  149         JR      NC,DOCLR
   80AC CD 66 80      [17]  150         CALL    SETSDA
   80AF 18 03         [12]  151         JR      AHEAD
   80B1                     152 DOCLR:
   80B1 CD 74 80      [17]  153         CALL    CLRSDA
   80B4                     154 AHEAD:
   80B4 CD 4A 80      [17]  155         CALL    SETSCL
   80B7 CD 58 80      [17]  156         CALL    CLRSCL
   80BA C9            [10]  157         RET
                            158 
                            159 ; I2C Write Byte routine
                            160 ; Takes A
                            161 ; Destroys B
                            162 ; Returns carry bit
   80BB                     163 I2CWBYTE:
   80BB 06 08         [ 7]  164         LD      B,8
   80BD                     165 ILOOP:
   80BD C5            [11]  166         PUSH    BC          ; save B
   80BE CB 07         [ 8]  167         RLC     A    
   80C0 F5            [11]  168         PUSH    AF          ; save A
   80C1 CD AA 80      [17]  169         CALL    I2CWBIT
   80C4 F1            [10]  170         POP     AF
   80C5 C1            [10]  171         POP     BC
   80C6 10 F5         [13]  172         DJNZ    ILOOP
   80C8 CD 9B 80      [17]  173         CALL    I2CRBIT
   80CB C9            [10]  174         RET
                            175 
                            176 ; I2C Read Byte routine
                            177 ; Destroys BC
                            178 ; Returns A
   80CC                     179 I2CRBYTE:
   80CC 06 08         [ 7]  180         LD      B,8
   80CE 0E 00         [ 7]  181         LD      C,0
   80D0                     182 LOOP3:
   80D0 C5            [11]  183         PUSH    BC
   80D1 CD 9B 80      [17]  184         CALL    I2CRBIT     ; get bit in carry flag
   80D4 C1            [10]  185         POP     BC
   80D5 CB 11         [ 8]  186         RL      C           ; rotate carry into bit0 of C register
   80D7 10 F7         [13]  187         DJNZ    LOOP3
   80D9 AF            [ 4]  188         XOR     A           ; clear carry flag              
   80DA C5            [11]  189         PUSH    BC
   80DB CD AA 80      [17]  190         CALL    I2CWBIT
   80DE C1            [10]  191         POP     BC
   80DF 79            [ 4]  192         LD      A,C
   80E0 C9            [10]  193         RET
                            194 ;
                            195 
                            196 ; Read 4-byte I2C Command from device into CMDBUF
                            197 ; Uses HL
                            198 ; Destroys A,BC,HL
   80E1                     199 I2CRREQ:
   80E1 CD 8A 80      [17]  200         CALL    I2CSTART
   80E4 3E 11         [ 7]  201         LD      A,I2CRADR
   80E6 CD BB 80      [17]  202         CALL    I2CWBYTE
   80E9 38 1A         [12]  203         JR      C,SKIP
   80EB CD CC 80      [17]  204         CALL    I2CRBYTE
   80EE DD 77 00      [19]  205         LD      (IX),A
   80F1 CD CC 80      [17]  206         CALL    I2CRBYTE
   80F4 DD 77 01      [19]  207         LD      (IX+1),A  
   80F7 CD CC 80      [17]  208         CALL    I2CRBYTE
   80FA DD 77 02      [19]  209         LD      (IX+2),A
   80FD CD CC 80      [17]  210         CALL    I2CRBYTE
   8100 DD 77 03      [19]  211         LD      (IX+3),A
   8103 18 14         [12]  212         JR      ENDI2C
                            213     
   8105                     214 SKIP:                       ; If no device present, fake an idle response
   8105 3E 2E         [ 7]  215         LD      A,0x2e  ; '.'
   8107 DD 77 00      [19]  216         LD      (IX),A
   810A 18 0D         [12]  217         JR      ENDI2C
                            218 
   810C                     219 I2CSRESP:
   810C F5            [11]  220         PUSH    AF
   810D CD 8A 80      [17]  221         CALL    I2CSTART
   8110 3E 10         [ 7]  222         LD      A,I2CWADR
   8112 CD BB 80      [17]  223         CALL    I2CWBYTE
   8115 F1            [10]  224         POP     AF
   8116 CD BB 80      [17]  225         CALL    I2CWBYTE
   8119                     226 ENDI2C:
   8119 CD 91 80      [17]  227         CALL    I2CSTOP
   811C C9            [10]  228         RET
                            229 ;
                            230 
                            231 ; Main Polling loop
                            232 ; Return carry flag if we got a valid command (not idle)
   811D                     233 POLL:
   811D CD E1 80      [17]  234         CALL    I2CRREQ
   8120 DD 7E 00      [19]  235         LD      A,(IX)
   8123 FE 52         [ 7]  236         CP      0x52    ; 'R' - Read memory
   8125 28 1B         [12]  237         JR      Z,MREAD
   8127 FE 57         [ 7]  238         CP      0x57    ; 'W' - Write memory
   8129 28 1D         [12]  239         JR      Z,MWRITE
   812B FE 49         [ 7]  240         CP      0x49    ; 'I' - Input from port
   812D 28 2D         [12]  241         JR      Z,PREAD
   812F FE 4F         [ 7]  242         CP      0x4F    ; 'O' - Output from port
   8131 28 30         [12]  243         JR      Z,PWRITE
   8133 FE 43         [ 7]  244         CP      0x43    ; 'C' - Call subroutine
   8135 28 3B         [12]  245         JR      Z,REMCALL
   8137 3F            [ 4]  246         CCF
   8138 C9            [10]  247         RET
   8139                     248 LOADHL:
   8139 DD 7E 01      [19]  249         LD      A,(IX+1)
   813C 67            [ 4]  250         LD      H,A
   813D DD 7E 02      [19]  251         LD      A,(IX+2)
   8140 6F            [ 4]  252         LD      L,A
   8141 C9            [10]  253         RET    
   8142                     254 MREAD:
   8142 CD 53 81      [17]  255         CALL    LOADBC
   8145 0A            [ 7]  256         LD      A,(BC)
   8146 18 25         [12]  257         JR      SRESP
   8148                     258 MWRITE:
   8148 CD 53 81      [17]  259         CALL    LOADBC
   814B DD 7E 03      [19]  260         LD      A,(IX+3)
   814E 02            [ 7]  261         LD      (BC),A
   814F 3E 57         [ 7]  262         LD      A,0x57  ;'W'
   8151 18 1A         [12]  263         JR      SRESP
   8153                     264 LOADBC:
   8153 DD 7E 01      [19]  265         LD      A,(IX+1)
   8156 47            [ 4]  266         LD      B,A
   8157 DD 7E 02      [19]  267         LD      A,(IX+2)
   815A 4F            [ 4]  268         LD      C,A
   815B C9            [10]  269         RET
   815C                     270 PREAD:
   815C CD 53 81      [17]  271         CALL    LOADBC
   815F ED 78         [12]  272         IN      A,(C)
   8161 18 0A         [12]  273         JR      SRESP
   8163                     274 PWRITE:
   8163 CD 53 81      [17]  275         CALL    LOADBC
   8166 DD 7E 03      [19]  276         LD      A,(IX+3)
   8169 ED 79         [12]  277         OUT     (C),A
   816B 3E 4F         [ 7]  278         LD      A,0x4F  ;'O'
   816D                     279 SRESP:
   816D CD 0C 81      [17]  280         CALL    I2CSRESP
   8170                     281 RHERE:
   8170 37            [ 4]  282         SCF
   8171 C9            [10]  283         RET
   8172                     284 REMCALL:
   8172 21 46 80      [10]  285         LD      HL,START
   8175 E5            [11]  286         PUSH    HL
   8176 CD 39 81      [17]  287         CALL    LOADHL
   8179 E9            [ 4]  288         JP      (HL)
                            289     
   817A                     290 INIT:
   817A 31 F0 77      [10]  291         LD      SP,SSTACK   ; have to set valid SP
   817D DD 21 F0 77   [14]  292         LD      IX,CMDBUF   ; Easy to index command buffer
                            293         
                            294 ; Main routine
   8181                     295 MAIN:
   8181 CD 1D 81      [17]  296         CALL    POLL
   8184 38 FB         [12]  297         JR      C,MAIN
                            298         
   8186 01 80 01      [10]  299         LD      BC,BIGDEL
   8189                     300 MLOOP:
   8189 0B            [ 6]  301         DEC     BC
   818A 79            [ 4]  302         LD      A,C
   818B B0            [ 4]  303         OR      B
   818C 20 FB         [12]  304         JR      NZ,MLOOP
   818E 18 F1         [12]  305         JR      MAIN
                            306 
                            307 
                            308     
                            309

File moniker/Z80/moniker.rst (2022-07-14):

                              1 ;
                              2 ; Moniker - Z80 Version
                              3 ; by Frank Palazzolo
                              4 ; For Sega Star Trek
                              5 ;
                              6 ; SCL  - OUT F9, bit7, (0x80) coin counter 1, pin 5, U11 - R1
                              7 ; DOUT - OUT F9, bit6, (0x40) coin counter 2, pin 9, U11 - R3
                              8 ; DIN  - IN  F8, bit3, (0x08) DIP, SW1, pin9, U2-pin 6
                              9 ;
                             10 ; Note: We cannot use opcode 0x32 on this platform, or it will trigger
                             11 ;       the security chip
                             12 ;
                             13         .area   CODE1   (ABS)   ; ASXXXX directive, absolute addressing
                             14 
                     00F8    15 DSPORT  .equ    0xf8        ; dip switch 1 port
                     00F9    16 CCPORT  .equ    0xf9        ; port for count counters
                             17 
                     CFF0    18 CMDBUF  .equ    0xcff0      ; Need only 4 bytes of ram for command buffer
                             19                             ; (We will save 12 more just in case)
                     CFF0    20 SSTACK  .equ    0xcff0      ; Start of stack
                             21 
                     0011    22 I2CRADR .equ    0x11        ; I2C read address  - I2C address 0x08
                     0010    23 I2CWADR .equ    0x10        ; I2C write address - I2C address 0x08
                             24 
                     0180    25 BIGDEL  .equ    0x0180      ; bigger delay, for now still fairly small
                             26 
   0000                      27         .org    0x0000
                             28     
   0000 F3            [ 4]   29 START:  DI                  ; Disable interrupts - we don't handle them
q  0001 3E 51         [ 7]   30         LD      A,81h
   0003 21 00 E0      [10]   31         LD      HL,0xE000
   0006 77            [ 7]   32         LD      (HL),A      ; blank the screen
   0007 C3 28 01      [10]   33         JP      INIT        ; go to initialization code
                             34     
                             35 ; Set the SCL pin high
                             36 ; D is the global coin counter buffer
                             37 ; Destroys A
   000A                      38 SETSCL:
   000A 7A            [ 4]   39         LD      A,D
   000B F6 80         [ 7]   40         OR      0x80
   000D 57            [ 4]   41         LD      D,A
   000E D3 F9         [11]   42         OUT     (CCPORT),A
   0010 CD 3A 00      [17]   43         CALL    I2CDELAY
   0013 C9            [10]   44         RET
                             45     
                             46 ; Set the SCL pin low
                             47 ; D is the global coin counter buffer
                             48 ; Destroys A
   0014                      49 CLRSCL:
   0014 7A            [ 4]   50         LD      A,D
   0015 E6 7F         [ 7]   51         AND     0x7F
   0017 57            [ 4]   52         LD      D,A
   0018 D3 F9         [11]   53         OUT     (CCPORT),A
   001A C9            [10]   54         RET
                             55 
                             56 ; Set the DOUT pin low
                             57 ; D is the global coin counter buffer
                             58 ; Destroys A 
   001B                      59 SETSDA:
   001B 7A            [ 4]   60         LD      A,D
   001C E6 BF         [ 7]   61         AND     0xBF
   001E 57            [ 4]   62         LD      D,A
   001F D3 F9         [11]   63         OUT     (CCPORT),A
   0021 CD 3A 00      [17]   64         CALL    I2CDELAY
   0024 C9            [10]   65         RET
                             66 
                             67 ; Set the DOUT pin high
                             68 ; D is the global coin counter buffer
                             69 ; Destroys A  
   0025                      70 CLRSDA:
   0025 7A            [ 4]   71         LD      A,D
   0026 F6 40         [ 7]   72         OR      0x40
   0028 57            [ 4]   73         LD      D,A
   0029 D3 F9         [11]   74         OUT     (CCPORT),A
   002B CD 3A 00      [17]   75         CALL    I2CDELAY
   002E C9            [10]   76         RET
                             77 
                             78 ; Read the DIN pin 
                             79 ; returns bit in carry flag    
   002F                      80 READSDA:
   002F DB F8         [11]   81         IN      A,(DSPORT)  ;0x08
   0031 CB 3F         [ 8]   82         SRL     A           ;0x04
   0033 CB 3F         [ 8]   83         SRL     A           ;0x02
   0035 CB 3F         [ 8]   84         SRL     A           ;0x01
   0037 CB 3F         [ 8]   85         SRL     A           ;carry flag
   0039 C9            [10]   86         RET
                             87     
                             88 ; Delay for half a bit time
   003A                      89 I2CDELAY:
   003A C9            [10]   90         RET     ; This is plenty
                             91 
                             92 ; I2C Start Condition
                             93 ; Uses HL
                             94 ; Destroys A
   003B                      95 I2CSTART:
   003B CD 25 00      [17]   96         CALL    CLRSDA      
   003E CD 14 00      [17]   97         CALL    CLRSCL
   0041 C9            [10]   98         RET
                             99 
                            100 ; I2C Stop Condition
                            101 ; Uses HL
                            102 ; Destroys A
   0042                     103 I2CSTOP:
   0042 CD 25 00      [17]  104         CALL    CLRSDA
   0045 CD 0A 00      [17]  105         CALL    SETSCL
   0048 CD 1B 00      [17]  106         CALL    SETSDA
   004B C9            [10]  107         RET
                            108 
                            109 ; I2C Read Bit routine
                            110 ; Returns bit in carry blag
                            111 ; Destroys A
   004C                     112 I2CRBIT:
   004C CD 1B 00      [17]  113         CALL    SETSDA
   004F CD 0A 00      [17]  114         CALL    SETSCL
   0052 CD 2F 00      [17]  115         CALL    READSDA
   0055 F5            [11]  116         PUSH    AF          ; save carry flag
   0056 CD 14 00      [17]  117         CALL    CLRSCL
   0059 F1            [10]  118         POP     AF          ; rv in carry flag
   005A C9            [10]  119         RET
                            120 
                            121 ; I2C Write Bit routine
                            122 ; Takes carry flag
                            123 ; Destroys A
   005B                     124 I2CWBIT:
   005B 30 05         [12]  125         JR      NC,DOCLR
   005D CD 1B 00      [17]  126         CALL    SETSDA
   0060 18 03         [12]  127         JR      AHEAD
   0062                     128 DOCLR:
   0062 CD 25 00      [17]  129         CALL    CLRSDA
   0065                     130 AHEAD:
   0065 CD 0A 00      [17]  131         CALL    SETSCL
   0068 CD 14 00      [17]  132         CALL    CLRSCL
   006B C9            [10]  133         RET
                            134         
                            135         ; Make sure this code ends before address 0x66 !
                            136         
   0066                     137         .org    0x0066
   0066 C3 00 00      [10]  138 NMI:    JP      START       ; restart on test button press
                            139 
                            140 ; I2C Write Byte routine
                            141 ; Takes A
                            142 ; Destroys B
                            143 ; Returns carry bit
   0069                     144 I2CWBYTE:
   0069 06 08         [ 7]  145         LD      B,8
   006B                     146 ILOOP:
   006B C5            [11]  147         PUSH    BC          ; save B
   006C CB 07         [ 8]  148         RLC     A    
   006E F5            [11]  149         PUSH    AF          ; save A
   006F CD 5B 00      [17]  150         CALL    I2CWBIT
   0072 F1            [10]  151         POP     AF
   0073 C1            [10]  152         POP     BC
   0074 10 F5         [13]  153         DJNZ    ILOOP
   0076 CD 4C 00      [17]  154         CALL    I2CRBIT
   0079 C9            [10]  155         RET
                            156 
                            157 ; I2C Read Byte routine
                            158 ; Destroys BC
                            159 ; Returns A
   007A                     160 I2CRBYTE:
   007A 06 08         [ 7]  161         LD      B,8
   007C 0E 00         [ 7]  162         LD      C,0
   007E                     163 LOOP3:
   007E C5            [11]  164         PUSH    BC
   007F CD 4C 00      [17]  165         CALL    I2CRBIT     ; get bit in carry flag
   0082 C1            [10]  166         POP     BC
   0083 CB 11         [ 8]  167         RL      C           ; rotate carry into bit0 of C register
   0085 10 F7         [13]  168         DJNZ    LOOP3
   0087 AF            [ 4]  169         XOR     A           ; clear carry flag              
   0088 C5            [11]  170         PUSH    BC
   0089 CD 5B 00      [17]  171         CALL    I2CWBIT
   008C C1            [10]  172         POP     BC
   008D 79            [ 4]  173         LD      A,C
   008E C9            [10]  174         RET
                            175 ;
                            176 
                            177 ; Read 4-byte I2C Command from device into CMDBUF
                            178 ; Uses HL
                            179 ; Destroys A,BC,HL
   008F                     180 I2CRREQ:
   008F CD 3B 00      [17]  181         CALL    I2CSTART
   0092 3E 11         [ 7]  182         LD      A,I2CRADR
   0094 CD 69 00      [17]  183         CALL    I2CWBYTE
   0097 38 1A         [12]  184         JR      C,SKIP
   0099 CD 7A 00      [17]  185         CALL    I2CRBYTE
   009C DD 77 00      [19]  186         LD      (IX),A
   009F CD 7A 00      [17]  187         CALL    I2CRBYTE
   00A2 DD 77 01      [19]  188         LD      (IX+1),A  
   00A5 CD 7A 00      [17]  189         CALL    I2CRBYTE
   00A8 DD 77 02      [19]  190         LD      (IX+2),A
   00AB CD 7A 00      [17]  191         CALL    I2CRBYTE
   00AE DD 77 03      [19]  192         LD      (IX+3),A
   00B1 18 14         [12]  193         JR      ENDI2C
                            194     
   00B3                     195 SKIP:                       ; If no device present, fake an idle response
   00B3 3E 2E         [ 7]  196         LD      A,0x2e  ; '.'
   00B5 DD 77 00      [19]  197         LD      (IX),A
   00B8 18 0D         [12]  198         JR      ENDI2C
                            199 
   00BA                     200 I2CSRESP:
   00BA F5            [11]  201         PUSH    AF
   00BB CD 3B 00      [17]  202         CALL    I2CSTART
   00BE 3E 10         [ 7]  203         LD      A,I2CWADR
   00C0 CD 69 00      [17]  204         CALL    I2CWBYTE
   00C3 F1            [10]  205         POP     AF
   00C4 CD 69 00      [17]  206         CALL    I2CWBYTE
   00C7                     207 ENDI2C:
   00C7 CD 42 00      [17]  208         CALL    I2CSTOP
   00CA C9            [10]  209         RET
                            210 ;
                            211 
                            212 ; Main Polling loop
                            213 ; Return carry flag if we got a valid command (not idle)
   00CB                     214 POLL:
   00CB CD 8F 00      [17]  215         CALL    I2CRREQ
   00CE DD 7E 00      [19]  216         LD      A,(IX)
   00D1 FE 52         [ 7]  217         CP      0x52    ; 'R' - Read memory
   00D3 28 1B         [12]  218         JR      Z,MREAD
   00D5 FE 57         [ 7]  219         CP      0x57    ; 'W' - Write memory
   00D7 28 1D         [12]  220         JR      Z,MWRITE
   00D9 FE 49         [ 7]  221         CP      0x49    ; 'I' - Input from port
   00DB 28 2D         [12]  222         JR      Z,PREAD
   00DD FE 4F         [ 7]  223         CP      0x4F    ; 'O' - Output from port
   00DF 28 30         [12]  224         JR      Z,PWRITE
   00E1 FE 43         [ 7]  225         CP      0x43    ; 'C' - Call subroutine
   00E3 28 3B         [12]  226         JR      Z,REMCALL
   00E5 3F            [ 4]  227         CCF
   00E6 C9            [10]  228         RET
   00E7                     229 LOADHL:
   00E7 DD 7E 01      [19]  230         LD      A,(IX+1)
   00EA 67            [ 4]  231         LD      H,A
   00EB DD 7E 02      [19]  232         LD      A,(IX+2)
   00EE 6F            [ 4]  233         LD      L,A
   00EF C9            [10]  234         RET    
   00F0                     235 MREAD:
   00F0 CD 01 01      [17]  236         CALL    LOADBC
   00F3 0A            [ 7]  237         LD      A,(BC)
   00F4 18 25         [12]  238         JR      SRESP
   00F6                     239 MWRITE:
   00F6 CD 01 01      [17]  240         CALL    LOADBC
   00F9 DD 7E 03      [19]  241         LD      A,(IX+3)
   00FC 02            [ 7]  242         LD      (BC),A
   00FD 3E 57         [ 7]  243         LD      A,0x57  ;'W'
   00FF 18 1A         [12]  244         JR      SRESP
   0101                     245 LOADBC:
   0101 DD 7E 01      [19]  246         LD      A,(IX+1)
   0104 47            [ 4]  247         LD      B,A
   0105 DD 7E 02      [19]  248         LD      A,(IX+2)
   0108 4F            [ 4]  249         LD      C,A
   0109 C9            [10]  250         RET
   010A                     251 PREAD:
   010A CD 01 01      [17]  252         CALL    LOADBC
   010D ED 78         [12]  253         IN      A,(C)
   010F 18 0A         [12]  254         JR      SRESP
   0111                     255 PWRITE:
   0111 CD 01 01      [17]  256         CALL    LOADBC
   0114 DD 7E 03      [19]  257         LD      A,(IX+3)
   0117 ED 79         [12]  258         OUT     (C),A
   0119 3E 4F         [ 7]  259         LD      A,0x4F  ;'O'
   011B                     260 SRESP:
   011B CD BA 00      [17]  261         CALL    I2CSRESP
   011E                     262 RHERE:
   011E 37            [ 4]  263         SCF
   011F C9            [10]  264         RET
   0120                     265 REMCALL:
   0120 21 00 00      [10]  266         LD      HL,START
   0123 E5            [11]  267         PUSH    HL
   0124 CD E7 00      [17]  268         CALL    LOADHL
   0127 E9            [ 4]  269         JP      (HL)
                            270     
   0128                     271 INIT:
   0128 31 F0 CF      [10]  272         LD      SP,SSTACK   ; have to set valid SP
   012B DD 21 F0 CF   [14]  273         LD      IX,CMDBUF   ; Easy to index command buffer
                            274         
                            275 ; Main routine
   012F                     276 MAIN:
   012F CD CB 00      [17]  277         CALL    POLL
   0132 38 FB         [12]  278         JR      C,MAIN
                            279         
   0134 01 80 01      [10]  280         LD      BC,BIGDEL
   0137                     281 MLOOP:
   0137 0B            [ 6]  282         DEC     BC
   0138 79            [ 4]  283         LD      A,C
   0139 B0            [ 4]  284         OR      B
   013A 20 FB         [12]  285         JR      NZ,MLOOP
   013C 18 F1         [12]  286         JR      MAIN
                            287 
                            288 
                            289     
                            290

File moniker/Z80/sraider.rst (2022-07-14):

                              1 ;
                              2 ; Moniker - Z80 Version
                              3 ; by Frank Palazzolo
                              4 ; For Space Raider - CPU2
                              5 ;
                              6         .area   CODE1   (ABS)   ; ASXXXX directive, absolute addressing
                              7 
                     2000     8 DATAIN	.equ	0x2000		; where to read data in from
                              9 
                     63F0    10 CMDBUF  .equ    0x63f0      ; Need only 4 bytes of ram for command buffer
                             11                             ; (We will save 12 more just in case)
                     63F0    12 SSTACK  .equ    0x63f0      ; Start of stack
                             13 
                     0011    14 I2CRADR .equ    0x11        ; I2C read address  - I2C address 0x08
                     0010    15 I2CWADR .equ    0x10        ; I2C write address - I2C address 0x08
                             16 
                     0180    17 BIGDEL  .equ    0x0180      ; bigger delay, for now still fairly small
                             18 
   0000                      19         .org    0x0000
                             20     
   0000 F3            [ 4]   21 START:  DI                  ; Disable interrupts - we don't handle them
   0001 C3 39 01      [10]   22         JP      INIT        ; go to initialization code
                             23     
                             24 ; Set the SCL pin high
                             25 ; D is the global buffer
                             26 ; Destroys A
   0004                      27 SETSCL:
   0004 7A            [ 4]   28         LD      A,D
   0005 F6 01         [ 7]   29         OR      0x01
   0007 57            [ 4]   30         LD      D,A
   0008 E5            [11]   31         PUSH    HL
   0009 26 40         [ 7]   32         LD      H,0x40
   000B 6F            [ 4]   33         LD      L,A
   000C 7E            [ 7]   34         LD      A,(HL)
   000D E1            [10]   35         POP     HL
   000E CD 43 00      [17]   36         CALL    I2CDELAY
   0011 C9            [10]   37         RET
                             38     
                             39 ; Set the SCL pin low
                             40 ; D is the global buffer
                             41 ; Destroys A
   0012                      42 CLRSCL:
   0012 7A            [ 4]   43         LD      A,D
   0013 E6 FE         [ 7]   44         AND     0xfe
   0015 57            [ 4]   45         LD      D,A
   0016 E5            [11]   46         PUSH    HL
   0017 26 40         [ 7]   47         LD      H,0x40
   0019 6F            [ 4]   48         LD      L,A
   001A 7E            [ 7]   49         LD      A,(HL)
   001B E1            [10]   50         POP     HL
   001C CD 43 00      [17]   51         CALL    I2CDELAY
   001F C9            [10]   52         RET
                             53 
                             54 ; Set the DOUT pin low
                             55 ; D is the global buffer
                             56 ; Destroys A 
   0020                      57 SETSDA:
   0020 7A            [ 4]   58         LD      A,D
   0021 E6 FD         [ 7]   59         AND     0xfd
   0023 57            [ 4]   60         LD      D,A
   0024 E5            [11]   61         PUSH    HL
   0025 26 40         [ 7]   62         LD      H,0x40
   0027 6F            [ 4]   63         LD      L,A
   0028 7E            [ 7]   64         LD      A,(HL)
   0029 E1            [10]   65         POP     HL
   002A CD 43 00      [17]   66         CALL    I2CDELAY
   002D C9            [10]   67         RET
                             68 
                             69 ; Set the DOUT pin high
                             70 ; D is the global buffer
                             71 ; Destroys A  
   002E                      72 CLRSDA:
   002E 7A            [ 4]   73         LD      A,D
   002F F6 02         [ 7]   74         OR      0x02
   0031 57            [ 4]   75         LD      D,A
   0032 E5            [11]   76         PUSH    HL
   0033 26 40         [ 7]   77         LD      H,0x40
   0035 6F            [ 4]   78         LD      L,A
   0036 7E            [ 7]   79         LD      A,(HL)
   0037 E1            [10]   80         POP     HL
   0038 CD 43 00      [17]   81         CALL    I2CDELAY
   003B C9            [10]   82         RET
                             83 
                             84 ; Read the DIN pin 
                             85 ; returns bit in carry flag    
   003C                      86 READSDA:
   003C 21 00 20      [10]   87         LD      HL,DATAIN
   003F 7E            [ 7]   88         LD      A,(HL)      ;perform a read into bit0
   0040 CB 3F         [ 8]   89         SRL     A           ;carry flag
   0042 C9            [10]   90         RET
                             91     
                             92 ; Delay for half a bit time
   0043                      93 I2CDELAY:
   0043 C9            [10]   94         RET     ; This is plenty
                             95 
                             96 ; I2C Start Condition
                             97 ; Uses HL
                             98 ; Destroys A
   0044                      99 I2CSTART:
   0044 CD 2E 00      [17]  100         CALL    CLRSDA      
   0047 CD 12 00      [17]  101         CALL    CLRSCL
   004A C9            [10]  102         RET
                            103 
                            104 ; I2C Stop Condition
                            105 ; Uses HL
                            106 ; Destroys A
   004B                     107 I2CSTOP:
   004B CD 2E 00      [17]  108         CALL    CLRSDA
   004E CD 04 00      [17]  109         CALL    SETSCL
   0051 CD 20 00      [17]  110         CALL    SETSDA
   0054 C9            [10]  111         RET
                            112 
                            113 ; I2C Read Bit routine
                            114 ; Returns bit in carry blag
                            115 ; Destroys A
   0055                     116 I2CRBIT:
   0055 CD 20 00      [17]  117         CALL    SETSDA
   0058 CD 04 00      [17]  118         CALL    SETSCL
   005B CD 3C 00      [17]  119         CALL    READSDA
   005E F5            [11]  120         PUSH    AF          ; save carry flag
   005F CD 12 00      [17]  121         CALL    CLRSCL
   0062 F1            [10]  122         POP     AF          ; rv in carry flag
   0063 C9            [10]  123         RET
                            124 
                            125         ; Make sure this code ends before address 0x66 !
                            126         
   0066                     127         .org    0x0066
   0066 C3 00 00      [10]  128 NMI:    JP      START       ; restart on NMI
                            129 
                            130 ; I2C Write Bit routine
                            131 ; Takes carry flag
                            132 ; Destroys A
   0069                     133 I2CWBIT:
   0069 30 05         [12]  134         JR      NC,DOCLR
   006B CD 20 00      [17]  135         CALL    SETSDA
   006E 18 03         [12]  136         JR      AHEAD
   0070                     137 DOCLR:
   0070 CD 2E 00      [17]  138         CALL    CLRSDA
   0073                     139 AHEAD:
   0073 CD 04 00      [17]  140         CALL    SETSCL
   0076 CD 12 00      [17]  141         CALL    CLRSCL
   0079 C9            [10]  142         RET
                            143 
                            144 ; I2C Write Byte routine
                            145 ; Takes A
                            146 ; Destroys B
                            147 ; Returns carry bit
   007A                     148 I2CWBYTE:
   007A 06 08         [ 7]  149         LD      B,8
   007C                     150 ILOOP:
   007C C5            [11]  151         PUSH    BC          ; save B
   007D CB 07         [ 8]  152         RLC     A    
   007F F5            [11]  153         PUSH    AF          ; save A
   0080 CD 69 00      [17]  154         CALL    I2CWBIT
   0083 F1            [10]  155         POP     AF
   0084 C1            [10]  156         POP     BC
   0085 10 F5         [13]  157         DJNZ    ILOOP
   0087 CD 55 00      [17]  158         CALL    I2CRBIT
   008A C9            [10]  159         RET
                            160 
                            161 ; I2C Read Byte routine
                            162 ; Destroys BC
                            163 ; Returns A
   008B                     164 I2CRBYTE:
   008B 06 08         [ 7]  165         LD      B,8
   008D 0E 00         [ 7]  166         LD      C,0
   008F                     167 LOOP3:
   008F C5            [11]  168         PUSH    BC
   0090 CD 55 00      [17]  169         CALL    I2CRBIT     ; get bit in carry flag
   0093 C1            [10]  170         POP     BC
   0094 CB 11         [ 8]  171         RL      C           ; rotate carry into bit0 of C register
   0096 10 F7         [13]  172         DJNZ    LOOP3
   0098 AF            [ 4]  173         XOR     A           ; clear carry flag              
   0099 C5            [11]  174         PUSH    BC
   009A CD 69 00      [17]  175         CALL    I2CWBIT
   009D C1            [10]  176         POP     BC
   009E 79            [ 4]  177         LD      A,C
   009F C9            [10]  178         RET
                            179 ;
                            180 
                            181 ; Read 4-byte I2C Command from device into CMDBUF
                            182 ; Uses HL
                            183 ; Destroys A,BC,HL
   00A0                     184 I2CRREQ:
   00A0 CD 44 00      [17]  185         CALL    I2CSTART
   00A3 3E 11         [ 7]  186         LD      A,I2CRADR
   00A5 CD 7A 00      [17]  187         CALL    I2CWBYTE
   00A8 38 1A         [12]  188         JR      C,SKIP
   00AA CD 8B 00      [17]  189         CALL    I2CRBYTE
   00AD DD 77 00      [19]  190         LD      (IX),A
   00B0 CD 8B 00      [17]  191         CALL    I2CRBYTE
   00B3 DD 77 01      [19]  192         LD      (IX+1),A  
   00B6 CD 8B 00      [17]  193         CALL    I2CRBYTE
   00B9 DD 77 02      [19]  194         LD      (IX+2),A
   00BC CD 8B 00      [17]  195         CALL    I2CRBYTE
   00BF DD 77 03      [19]  196         LD      (IX+3),A
   00C2 18 14         [12]  197         JR      ENDI2C
                            198     
   00C4                     199 SKIP:                       ; If no device present, fake an idle response
   00C4 3E 2E         [ 7]  200         LD      A,0x2e  ; '.'
   00C6 DD 77 00      [19]  201         LD      (IX),A
   00C9 18 0D         [12]  202         JR      ENDI2C
                            203 
   00CB                     204 I2CSRESP:
   00CB F5            [11]  205         PUSH    AF
   00CC CD 44 00      [17]  206         CALL    I2CSTART
   00CF 3E 10         [ 7]  207         LD      A,I2CWADR
   00D1 CD 7A 00      [17]  208         CALL    I2CWBYTE
   00D4 F1            [10]  209         POP     AF
   00D5 CD 7A 00      [17]  210         CALL    I2CWBYTE
   00D8                     211 ENDI2C:
   00D8 CD 4B 00      [17]  212         CALL    I2CSTOP
   00DB C9            [10]  213         RET
                            214 ;
                            215 
                            216 ; Main Polling loop
                            217 ; Return carry flag if we got a valid command (not idle)
   00DC                     218 POLL:
   00DC CD A0 00      [17]  219         CALL    I2CRREQ
   00DF DD 7E 00      [19]  220         LD      A,(IX)
   00E2 FE 52         [ 7]  221         CP      0x52    ; 'R' - Read memory
   00E4 28 1B         [12]  222         JR      Z,MREAD
   00E6 FE 57         [ 7]  223         CP      0x57    ; 'W' - Write memory
   00E8 28 1D         [12]  224         JR      Z,MWRITE
   00EA FE 49         [ 7]  225         CP      0x49    ; 'I' - Input from port
   00EC 28 2D         [12]  226         JR      Z,PREAD
   00EE FE 4F         [ 7]  227         CP      0x4F    ; 'O' - Output from port
   00F0 28 30         [12]  228         JR      Z,PWRITE
   00F2 FE 43         [ 7]  229         CP      0x43    ; 'C' - Call subroutine
   00F4 28 3B         [12]  230         JR      Z,REMCALL
   00F6 3F            [ 4]  231         CCF
   00F7 C9            [10]  232         RET
   00F8                     233 LOADHL:
   00F8 DD 7E 01      [19]  234         LD      A,(IX+1)
   00FB 67            [ 4]  235         LD      H,A
   00FC DD 7E 02      [19]  236         LD      A,(IX+2)
   00FF 6F            [ 4]  237         LD      L,A
   0100 C9            [10]  238         RET    
   0101                     239 MREAD:
   0101 CD 12 01      [17]  240         CALL    LOADBC
   0104 0A            [ 7]  241         LD      A,(BC)
   0105 18 25         [12]  242         JR      SRESP
   0107                     243 MWRITE:
   0107 CD 12 01      [17]  244         CALL    LOADBC
   010A DD 7E 03      [19]  245         LD      A,(IX+3)
   010D 02            [ 7]  246         LD      (BC),A
   010E 3E 57         [ 7]  247         LD      A,0x57  ;'W'
   0110 18 1A         [12]  248         JR      SRESP
   0112                     249 LOADBC:
   0112 DD 7E 01      [19]  250         LD      A,(IX+1)
   0115 47            [ 4]  251         LD      B,A
   0116 DD 7E 02      [19]  252         LD      A,(IX+2)
   0119 4F            [ 4]  253         LD      C,A
   011A C9            [10]  254         RET
   011B                     255 PREAD:
   011B CD 12 01      [17]  256         CALL    LOADBC
   011E ED 78         [12]  257         IN      A,(C)
   0120 18 0A         [12]  258         JR      SRESP
   0122                     259 PWRITE:
   0122 CD 12 01      [17]  260         CALL    LOADBC
   0125 DD 7E 03      [19]  261         LD      A,(IX+3)
   0128 ED 79         [12]  262         OUT     (C),A
   012A 3E 4F         [ 7]  263         LD      A,0x4F  ;'O'
   012C                     264 SRESP:
   012C CD CB 00      [17]  265         CALL    I2CSRESP
   012F                     266 RHERE:
   012F 37            [ 4]  267         SCF
   0130 C9            [10]  268         RET
   0131                     269 REMCALL:
   0131 21 00 00      [10]  270         LD      HL,START
   0134 E5            [11]  271         PUSH    HL
   0135 CD F8 00      [17]  272         CALL    LOADHL
   0138 E9            [ 4]  273         JP      (HL)
                            274     
   0139                     275 INIT:
   0139 31 F0 63      [10]  276         LD      SP,SSTACK   ; have to set valid SP
   013C DD 21 F0 63   [14]  277         LD      IX,CMDBUF   ; Easy to index command buffer
                            278         
                            279 ; Main routine
   0140                     280 MAIN:
   0140 CD DC 00      [17]  281         CALL    POLL
   0143 38 FB         [12]  282         JR      C,MAIN
                            283         
   0145 01 80 01      [10]  284         LD      BC,BIGDEL
   0148                     285 MLOOP:
   0148 0B            [ 6]  286         DEC     BC
   0149 79            [ 4]  287         LD      A,C
   014A B0            [ 4]  288         OR      B
   014B 20 FB         [12]  289         JR      NZ,MLOOP
   014D 18 F1         [12]  290         JR      MAIN
                            291 
                            292 
                            293     
                            294

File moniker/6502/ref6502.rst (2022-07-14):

                              1 ;
                              2 ; Moniker - 6502 Version
                              3 ; by Frank Palazzolo
                              4 ; For ROM IO Hardware
                              5 ;
                              6         .area   CODE1   (ABS)   ; ASXXXX directive, absolute addressing
                              7 
                              8 ;;;;;;;;;;;;;;;;;;;;;;;;;;;;;;;;;;;;;;;;;;;;;;;;;;;;;;;;;;;;;;;;;;;;;;;;;;;
                              9 ; You may need to adjust these variables for different targets
                             10 ;;;;;;;;;;;;;;;;;;;;;;;;;;;;;;;;;;;;;;;;;;;;;;;;;;;;;;;;;;;;;;;;;;;;;;;;;;;
                             11 
                             12 ; RAM SETTINGS - usually in zero page
                             13 
                     0000    14 RAMSTRT .equ    0x00    ;start of ram, needs 7 bytes starting here
                     00FF    15 SSTACK	.equ	0xff	;start of stack, needs some memory below this address
                             16 
                             17 ; ROM SETTINGS - usually the last 2K of memory for 6502
                             18 
                     F800    19 SCHIP   .equ     0xf800   ;start of chip memory mapping
                             20 
                     FFA0    21 IOREGR	.equ	SCHIP+0x07a0	;reserved region for IO Read
                     FFC0    22 IOREGW	.equ	SCHIP+0x07c0	;reserved region for IO Write
                     FFFA    23 VECTORS	.equ	SCHIP+0x07fa	;reserved for vectors
                             24 
                             25 ; TIMER SETTING
                     0180    26 BIGDEL	.equ	0x0180   ;delay factor
                             27 
                     0011    28 I2CRADR .equ     0x11    ;I2C read address  - I2C address 0x08
                     0010    29 I2CWADR .equ     0x10    ;I2C write address - I2C address 0x08
                             30 
                             31 ;;;;;;;;;;;;;;;;;;;;;;;;;;;;;;;;;;;;;;;;;;;;;;;;;;;;;;;;;;;;;;;;;;;;;;;;;;;
                             32 ; RAM Variables	
                             33 ;;;;;;;;;;;;;;;;;;;;;;;;;;;;;;;;;;;;;;;;;;;;;;;;;;;;;;;;;;;;;;;;;;;;;;;;;;;
                             34 
                     0000    35 OUTBUF	.equ	RAMSTRT	        ;buffer for output states
                     0001    36 B	.equ	RAMSTRT+0x01	;general purpose
                     0002    37 C	.equ	RAMSTRT+0x02	;general purpose
                     0003    38 CMDBUF0 .equ	RAMSTRT+0x03	;command buffer
                     0004    39 CMDBUF1 .equ	RAMSTRT+0x04	;command buffer
                     0005    40 CMDBUF2 .equ	RAMSTRT+0x05	;command buffer
                     0006    41 CMDBUF3 .equ	RAMSTRT+0x06	;command buffer
                             42 
   F800                      43 	.org	SCHIP	;last 2K of memory starts here
                             44 
                             45 ;;;;;;;;;;;;;;;;;;;;;;;;;;;;;;;;;;;;;;;;;;;;;;;;;;;;;;;;;;;;;;;;;;;;;;;;;;;
                             46 ; This function is called once, and should be used do any game-specific
                             47 ; initialization that is required
                             48 ;;;;;;;;;;;;;;;;;;;;;;;;;;;;;;;;;;;;;;;;;;;;;;;;;;;;;;;;;;;;;;;;;;;;;;;;;;;
                             49 
   F800                      50 ONCE:
                             51 ;       YOUR CODE CAN GO HERE
   F800 60            [ 6]   52         rts
                             53 
                             54 ;;;;;;;;;;;;;;;;;;;;;;;;;;;;;;;;;;;;;;;;;;;;;;;;;;;;;;;;;;;;;;;;;;;;;;;;;;;
                             55 ; This function is called every time during the polling loop.  It can be
                             56 ; used to run watchdog code, etc.  I have provided a simple delay loop
                             57 ; so that the I2C slave is not overwhelmed
                             58 ;;;;;;;;;;;;;;;;;;;;;;;;;;;;;;;;;;;;;;;;;;;;;;;;;;;;;;;;;;;;;;;;;;;;;;;;;;;
                             59 
   F801                      60 EVERY:
                             61 ;       YOUR CODE CAN GO HERE
   F801 60            [ 6]   62         rts
                             63 
                             64 ;;;;;;;;;;;;;;;;;;;;;;;;;;;;;;;;;;;;;;;;;;;;;;;;;;;;;;;;;;;;;;;;;;;;;;
                             65 ; Main Program code starts here
                             66 ;;;;;;;;;;;;;;;;;;;;;;;;;;;;;;;;;;;;;;;;;;;;;;;;;;;;;;;;;;;;;;;;;;;;;;
                             67 
                             68 ; NMI Handler
   F802 40            [ 6]   69 NMI:	rti             ;Don't do anything on an NMI
                             70 
   F803 A5 00         [ 3]   71 SETSCL:	lda	OUTBUF
   F805 09 01         [ 2]   72 	ora	#0x01
   F807 85 00         [ 3]   73         sta     OUTBUF
   F809 AA            [ 2]   74         tax
   F80A BD C0 FF      [ 5]   75         lda     IOREGW,X
   F80D 20 3F F8      [ 6]   76 	jsr	I2CDLY
   F810 60            [ 6]   77 	rts
                             78 
   F811 A5 00         [ 3]   79 CLRSCL:	lda	OUTBUF
   F813 29 1E         [ 2]   80 	and	#0x1e
   F815 85 00         [ 3]   81 	sta	OUTBUF
   F817 AA            [ 2]   82         tax
   F818 BD C0 FF      [ 5]   83         lda     IOREGW,X
   F81B 60            [ 6]   84 	rts
                             85 
   F81C A5 00         [ 3]   86 SETSDA:	lda	OUTBUF
   F81E 29 1D         [ 2]   87 	and	#0x1d
   F820 85 00         [ 3]   88         sta     OUTBUF
   F822 AA            [ 2]   89         tax
   F823 BD C0 FF      [ 5]   90         lda     IOREGW,X
   F826 20 3F F8      [ 6]   91 	jsr	I2CDLY
   F829 60            [ 6]   92 	rts
                             93 
   F82A A5 00         [ 3]   94 CLRSDA:	lda	OUTBUF
   F82C 09 02         [ 2]   95 	ora	#0x02
   F82E 85 00         [ 3]   96         sta     OUTBUF
   F830 AA            [ 2]   97         tax
   F831 BD C0 FF      [ 5]   98         lda     IOREGW,X
   F834 20 3F F8      [ 6]   99 	jsr	I2CDLY
   F837 60            [ 6]  100 	rts
                            101 
   F838 A6 00         [ 3]  102 READSDA:	ldx	OUTBUF
   F83A BD A0 FF      [ 5]  103         lda     IOREGR,X
   F83D 6A            [ 2]  104         ror
   F83E 60            [ 6]  105 	rts				
                            106 
                            107 ; Delay for half a bit time
   F83F 60            [ 6]  108 I2CDLY:	rts		; TBD - this is plenty?
                            109 
                            110 ; I2C Start Condition
   F840                     111 I2CSTART:
   F840 20 2A F8      [ 6]  112         jsr    CLRSDA      
   F843 20 11 F8      [ 6]  113         jsr    CLRSCL
   F846 60            [ 6]  114         rts
                            115 
                            116 ; I2C Stop Condition
                            117 ; Uses HL
                            118 ; Destroys A
   F847                     119 I2CSTOP:
   F847 20 2A F8      [ 6]  120         jsr    CLRSDA
   F84A 20 03 F8      [ 6]  121         jsr    SETSCL
   F84D 20 1C F8      [ 6]  122         jsr    SETSDA
   F850 60            [ 6]  123         rts
                            124         
   F851                     125 I2CRBIT:
   F851 20 1C F8      [ 6]  126 	jsr	SETSDA
   F854 20 03 F8      [ 6]  127 	jsr	SETSCL
   F857 20 38 F8      [ 6]  128 	jsr	READSDA	; sets/clears carry flag
   F85A 20 11 F8      [ 6]  129 	jsr     CLRSCL
   F85D 60            [ 6]  130 	rts		; carry flag still good here
                            131 
   F85E                     132 I2CWBIT:
   F85E 90 06         [ 4]  133 	bcc	DOCLR
   F860 20 1C F8      [ 6]  134 	jsr	SETSDA
   F863 4C 69 F8      [ 3]  135 	jmp	AHEAD
   F866                     136 DOCLR:
   F866 20 2A F8      [ 6]  137 	jsr	CLRSDA
   F869                     138 AHEAD:
   F869 20 03 F8      [ 6]  139 	jsr	SETSCL
   F86C 20 11 F8      [ 6]  140 	jsr	CLRSCL
   F86F 60            [ 6]  141 	rts
                            142         
   F870                     143 I2CWBYTE:
   F870 48            [ 3]  144 	pha
   F871 A9 08         [ 2]  145 	lda	#0x08
   F873 85 01         [ 3]  146 	sta	B
   F875 68            [ 4]  147 	pla
   F876                     148 ILOOP:
   F876 2A            [ 2]  149 	rol
   F877 48            [ 3]  150 	pha
   F878 20 5E F8      [ 6]  151 	jsr	I2CWBIT
   F87B 68            [ 4]  152 	pla
   F87C C6 01         [ 5]  153 	dec	B
   F87E D0 F6         [ 4]  154 	bne	ILOOP
   F880 20 51 F8      [ 6]  155 	jsr	I2CRBIT
   F883 60            [ 6]  156 	rts
                            157 	
   F884                     158 I2CRBYTE:
   F884 A9 08         [ 2]  159         lda	#0x08
   F886 85 01         [ 3]  160 	sta	B
   F888 A9 00         [ 2]  161 	lda	#0x00
   F88A 85 02         [ 3]  162 	sta	C
   F88C                     163 LOOP3:
   F88C 20 51 F8      [ 6]  164         jsr     I2CRBIT     ; get bit in carry flag
   F88F 26 02         [ 5]  165         rol     C           ; rotate carry into bit0 of C register
   F891 C6 01         [ 5]  166         dec	B
   F893 D0 F7         [ 4]  167         bne    	LOOP3
   F895 18            [ 2]  168         clc           	    ; clear carry flag              
   F896 20 5E F8      [ 6]  169         jsr   	I2CWBIT
   F899 A5 02         [ 3]  170         lda  	C
   F89B 60            [ 6]  171         rts
                            172 
   F89C                     173 I2CRREQ:
   F89C 20 40 F8      [ 6]  174         jsr     I2CSTART
   F89F A9 11         [ 2]  175         lda	#I2CRADR
   F8A1 20 70 F8      [ 6]  176         jsr     I2CWBYTE
   F8A4 B0 17         [ 4]  177         bcs     SKIP
   F8A6 20 84 F8      [ 6]  178         jsr     I2CRBYTE
   F8A9 85 03         [ 3]  179         sta     CMDBUF0
   F8AB 20 84 F8      [ 6]  180         jsr     I2CRBYTE
   F8AE 85 04         [ 3]  181         sta     CMDBUF1
   F8B0 20 84 F8      [ 6]  182         jsr     I2CRBYTE
   F8B3 85 05         [ 3]  183         sta     CMDBUF2
   F8B5 20 84 F8      [ 6]  184         jsr     I2CRBYTE
   F8B8 85 06         [ 3]  185         sta     CMDBUF3
   F8BA 4C D1 F8      [ 3]  186         jmp     ENDI2C
                            187     
   F8BD                     188 SKIP:                       ; If no device present, fake an idle response
   F8BD A9 2E         [ 2]  189         lda     #0x2e  ; '.'
   F8BF 85 03         [ 3]  190         sta     CMDBUF0
   F8C1 4C D1 F8      [ 3]  191         jmp     ENDI2C
                            192 
   F8C4                     193 I2CSRESP:
   F8C4 48            [ 3]  194         pha
   F8C5 20 40 F8      [ 6]  195         jsr     I2CSTART
   F8C8 A9 10         [ 2]  196         lda     #I2CWADR
   F8CA 20 70 F8      [ 6]  197         jsr     I2CWBYTE
   F8CD 68            [ 4]  198         pla
   F8CE 20 70 F8      [ 6]  199         jsr     I2CWBYTE
   F8D1                     200 ENDI2C:
   F8D1 20 47 F8      [ 6]  201         jsr     I2CSTOP
   F8D4 60            [ 6]  202         rts
                            203 
   F8D5                     204 POLL:
   F8D5 20 9C F8      [ 6]  205         jsr     I2CRREQ
   F8D8 A5 03         [ 3]  206         lda     CMDBUF0
   F8DA C9 52         [ 2]  207         cmp     #0x52    	; 'R' - Read memory
   F8DC F0 0A         [ 4]  208         beq     MREAD
   F8DE C9 57         [ 2]  209         cmp     #0x57    	; 'W' - Write memory
   F8E0 F0 10         [ 4]  210         beq	MWRITE
   F8E2 C9 43         [ 2]  211         cmp     #0x43    	; 'C' - Call subroutine
   F8E4 F0 26         [ 4]  212         beq	REMCALL
   F8E6 18            [ 2]  213         clc
   F8E7 60            [ 6]  214         rts
                            215 
   F8E8                     216 MREAD:
   F8E8 20 FE F8      [ 6]  217         jsr     LOADBC
   F8EB A0 00         [ 2]  218         ldy	#0x00
   F8ED B1 01         [ 6]  219         lda	[B],Y
   F8EF 4C 07 F9      [ 3]  220         jmp     SRESP
   F8F2                     221 MWRITE:
   F8F2 20 FE F8      [ 6]  222         jsr     LOADBC
   F8F5 A5 06         [ 3]  223         lda     CMDBUF3
   F8F7 91 01         [ 6]  224         sta     [B],Y
   F8F9 A9 57         [ 2]  225         lda     #0x57  	;'W'
   F8FB 4C 07 F9      [ 3]  226         jmp     SRESP
   F8FE                     227 LOADBC:
   F8FE A5 05         [ 3]  228 	lda	CMDBUF2
   F900 85 01         [ 3]  229 	sta	B
   F902 A5 04         [ 3]  230 	lda	CMDBUF1
   F904 85 02         [ 3]  231 	sta	C
   F906 60            [ 6]  232 	rts
                            233 	
   F907                     234 SRESP:
   F907 20 C4 F8      [ 6]  235         jsr    I2CSRESP
   F90A                     236 RHERE:
   F90A 38            [ 2]  237         sec
   F90B 60            [ 6]  238         rts
   F90C                     239 REMCALL:
   F90C A9 F9         [ 2]  240 	lda	#>(START-1)
   F90E 48            [ 3]  241         pha
   F90F A9 17         [ 2]  242         lda	#<(START-1)
   F911 48            [ 3]  243         pha
   F912 20 FE F8      [ 6]  244         jsr     LOADBC
   F915 6C 01 00      [ 5]  245         jmp     [B]
                            246         
                            247 ;;;;;;;;;;
                            248 	
   F918                     249 START:
   F918 78            [ 2]  250         sei             ; disable interrupts
   F919 A2 FF         [ 2]  251 	ldx	#SSTACK
   F91B 9A            [ 2]  252 	txs		; Init stack
   F91C D8            [ 2]  253 	cld		; No Decimal
   F91D A9 00         [ 2]  254         lda     #0x00
   F91F 85 00         [ 3]  255         sta     OUTBUF
   F921 20 00 F8      [ 6]  256         jsr     ONCE
                            257 
                            258 ; Main routine
   F924                     259 MAIN:
   F924 20 01 F8      [ 6]  260         jsr     EVERY
   F927 20 D5 F8      [ 6]  261         jsr     POLL
   F92A B0 F8         [ 4]  262         bcs     MAIN
   F92C A9 01         [ 2]  263         lda	#BIGDEL>>8
   F92E 85 01         [ 3]  264         sta	B
   F930 A9 80         [ 2]  265         lda	#BIGDEL%256
   F932 85 02         [ 3]  266         sta	C
   F934                     267 MLOOP:
   F934 A5 02         [ 3]  268         lda	C
   F936 F0 05         [ 4]  269         beq	DECBOTH
   F938 C6 02         [ 5]  270         dec	C
   F93A 4C 34 F9      [ 3]  271         jmp	MLOOP
   F93D                     272 DECBOTH:
   F93D A5 01         [ 3]  273 	lda	B
   F93F F0 E3         [ 4]  274 	beq	MAIN
   F941 C6 02         [ 5]  275 	dec	C
   F943 C6 01         [ 5]  276 	dec	B
   F945 4C 34 F9      [ 3]  277 	jmp	MLOOP
                            278 
   FFC0                     279         .org    IOREGW
                            280         
   FFC0 00 01 02 03 04 05   281         .DB     0x00,0x01,0x02,0x03,0x04,0x05,0x06,0x07,0x08,0x09,0x0a,0x0b,0x0c,0x0d,0x0e,0x0f
        06 07 08 09 0A 0B
        0C 0D 0E 0F
   FFD0 10 11 12 13 14 15   282         .DB     0x10,0x11,0x12,0x13,0x14,0x15,0x16,0x17,0x18,0x19,0x1a,0x1b,0x1c,0x1d,0x1e,0x1f
        16 17 18 19 1A 1B
        1C 1D 1E 1F
                            283 
                            284 ;       vectors
                            285 
   FFFA                     286 	.org	SCHIP+0x07fa
                            287 
   FFFA 02 F8               288 	.dw	NMI
   FFFC 18 F9               289 	.dw	START
   FFFE 18 F9               290 	.dw	START
                            291 	
                            292 	
                            293

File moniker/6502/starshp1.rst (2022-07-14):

                              1 ;
                              2 ; Moniker - 6502 Version
                              3 ; by Frank Palazzolo
                              4 ; For ROM IO Hardware
                              5 ;
                              6         .area   CODE1   (ABS)   ; ASXXXX directive, absolute addressing
                              7 
                              8 ;;;;;;;;;;;;;;;;;;;;;;;;;;;;;;;;;;;;;;;;;;;;;;;;;;;;;;;;;;;;;;;;;;;;;;;;;;;
                              9 ; You may need to adjust these variables for different targets
                             10 ;;;;;;;;;;;;;;;;;;;;;;;;;;;;;;;;;;;;;;;;;;;;;;;;;;;;;;;;;;;;;;;;;;;;;;;;;;;
                             11 
                             12 ; RAM SETTINGS - usually in zero page
                             13 
                     0000    14 RAMSTRT .equ    0x00    ;start of ram, needs 7 bytes starting here
                     00FF    15 SSTACK	.equ	0xff	;start of stack, needs some memory below this address
                             16 
                             17 ; ROM SETTINGS - usually the last 2K of memory for 6502
                             18 
                     F800    19 SCHIP   .equ     0xf800   ;start of chip memory mapping
                             20 
                     FFA0    21 IOREGR	.equ	SCHIP+0x07a0	;reserved region for IO Read
                     FFC0    22 IOREGW	.equ	SCHIP+0x07c0	;reserved region for IO Write
                     FFFA    23 VECTORS	.equ	SCHIP+0x07fa	;reserved for vectors
                             24 
                             25 ; TIMER SETTING
                     0180    26 BIGDEL	.equ	0x0180   ;delay factor
                             27 
                     0011    28 I2CRADR .equ     0x11    ;I2C read address  - I2C address 0x08
                     0010    29 I2CWADR .equ     0x10    ;I2C write address - I2C address 0x08
                             30 
                             31 ;;;;;;;;;;;;;;;;;;;;;;;;;;;;;;;;;;;;;;;;;;;;;;;;;;;;;;;;;;;;;;;;;;;;;;;;;;;
                             32 ; RAM Variables	
                             33 ;;;;;;;;;;;;;;;;;;;;;;;;;;;;;;;;;;;;;;;;;;;;;;;;;;;;;;;;;;;;;;;;;;;;;;;;;;;
                             34 
                     0000    35 OUTBUF	.equ	RAMSTRT	        ;buffer for output states
                     0001    36 B	.equ	RAMSTRT+0x01	;general purpose
                     0002    37 C	.equ	RAMSTRT+0x02	;general purpose
                     0003    38 CMDBUF0 .equ	RAMSTRT+0x03	;command buffer
                     0004    39 CMDBUF1 .equ	RAMSTRT+0x04	;command buffer
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

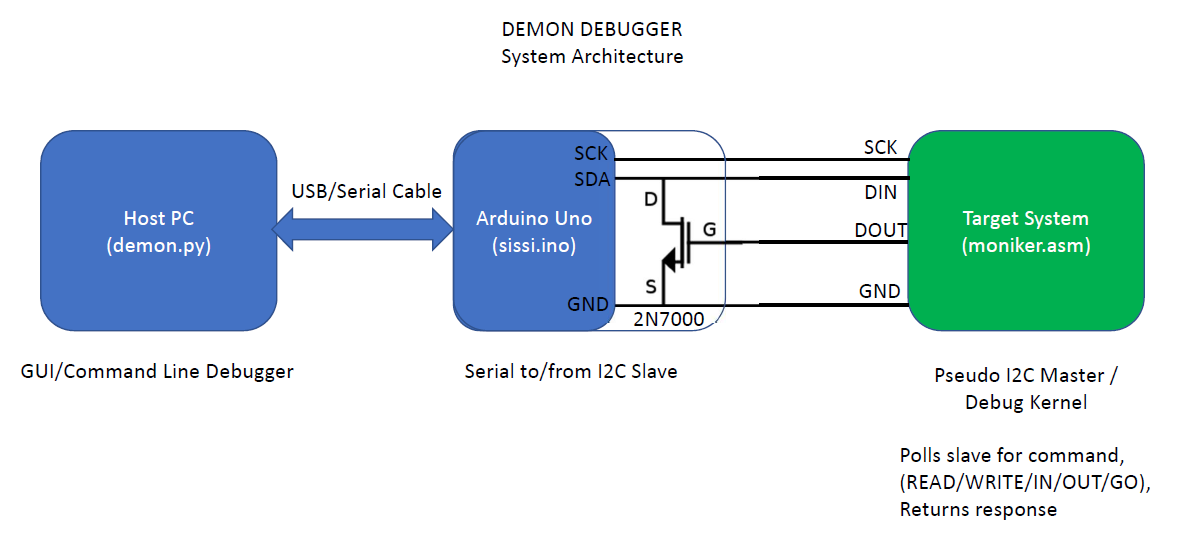
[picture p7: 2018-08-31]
img/demon_arch.png

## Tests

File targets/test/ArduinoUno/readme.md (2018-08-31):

# Arduino Uno moniker target - for testing purposes only

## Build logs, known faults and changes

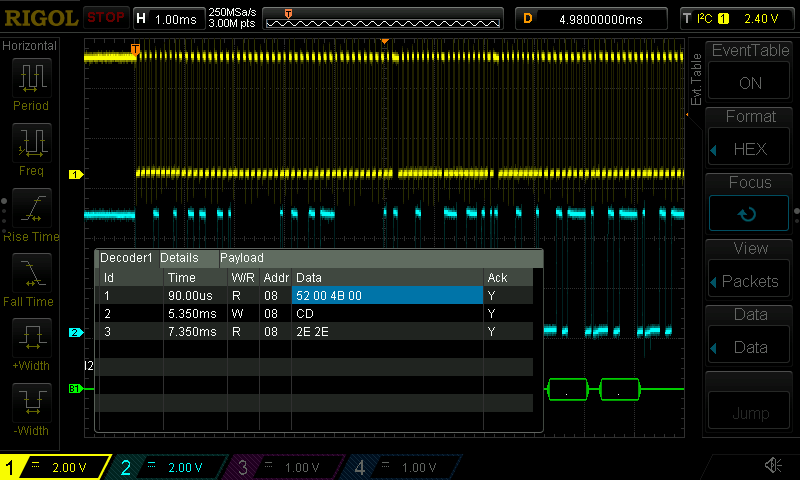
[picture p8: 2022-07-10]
img/DemonDebuggerReadMemory004B.png

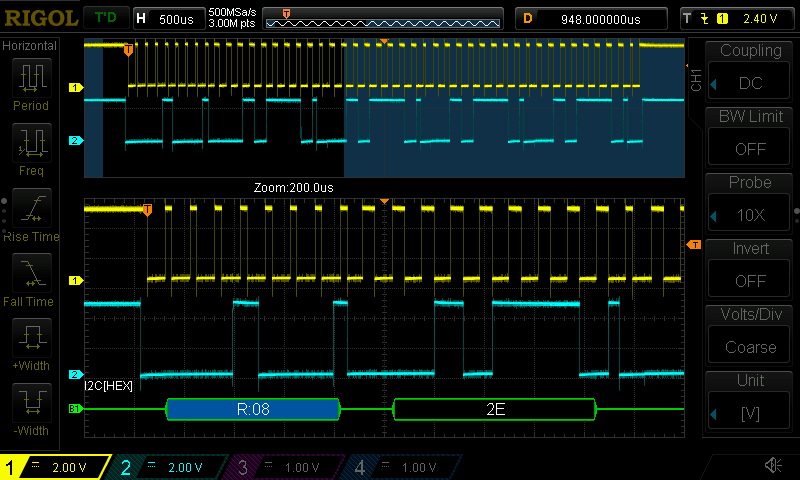
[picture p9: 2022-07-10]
img/DemonDebuggerFirstHalf.png

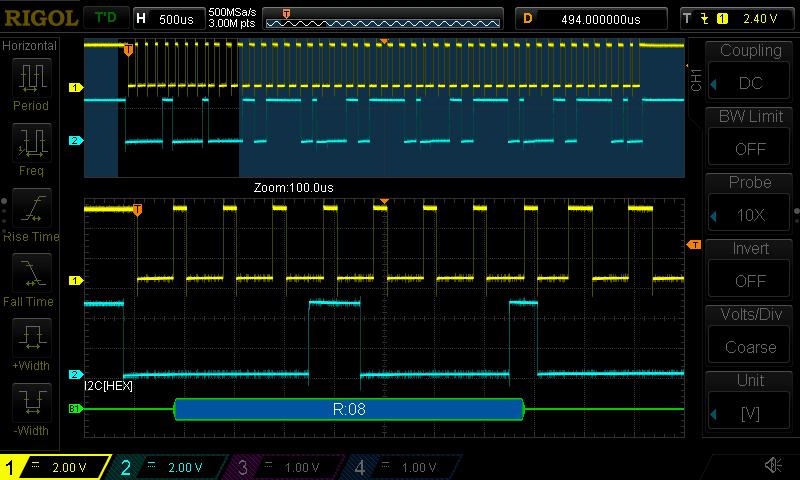
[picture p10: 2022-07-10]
img/DemonDebuggerReadAddress.png

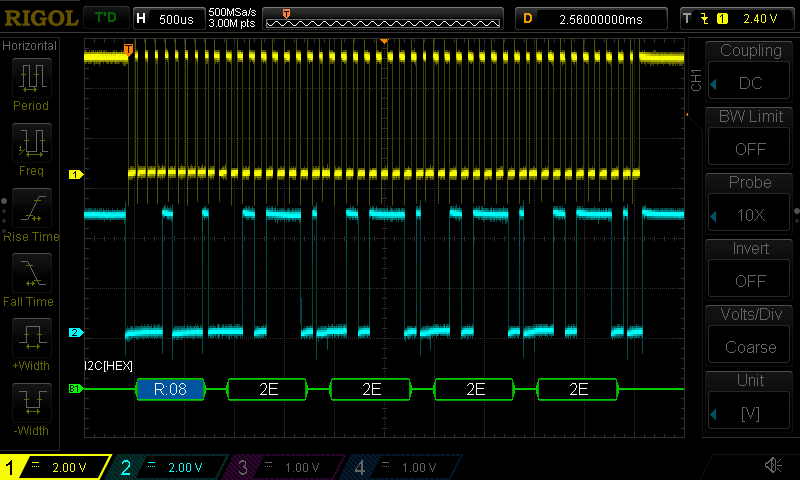
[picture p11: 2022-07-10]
img/DemonDebuggerFullHex.png

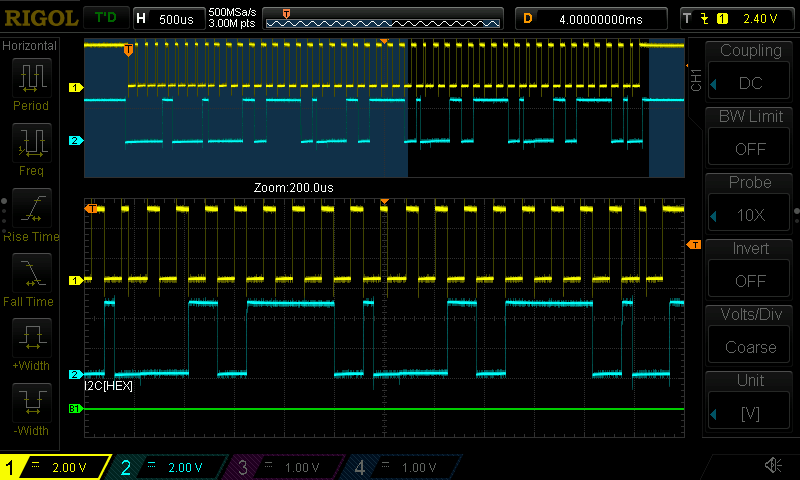
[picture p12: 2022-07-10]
img/DemonDebuggerLastHalf.png

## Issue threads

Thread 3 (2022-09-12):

Ribbon to PDIP 24 connector

srwalter, 2022-09-12:
What's the part number for the ribbon cable to PDIP-24 adapter?  What would you even call that?

Nice talk at VCFMW, by the way

abzman, 2022-09-12:
I used this for one end of the cable: https://www.lcsc.com/product-detail/IDC-Connectors_JILN-531424YBS0BW01_C601916.html

As for the cable it's just a strip of 24 pin ribbon, technically it's 0.05" pitch, but in reality it's just a bit of ide or floppy ribbon cable that's been peeled back to 24 pins.

Frank sourced the ribbon to dip parts I think.

palazzol, 2022-09-12:
Going back through my order history, looks like it was this part from Mouser:
[https://www.mouser.com/ProductDetail/629-CWR-130-24-0000](https://www.mouser.com/ProductDetail/629-CWR-130-24-0000)

srwalter, 2022-09-13:
Thanks!

Closed 2022-09-13.

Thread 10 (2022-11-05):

inhibit programming when target power is present

palazzol, 2022-11-05:
requires additional command on arduino side to read analog voltage and python code to inhibit programming if enough voltage is present

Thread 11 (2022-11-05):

glitches on 6809

palazzol, 2022-11-05:
experimental board rev E to fix it, see [commit  here](https://github.com/palazzol/demon/commit/47c935433c3131f8dde88b7b2844f0d14d495991)

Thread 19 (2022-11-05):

rev e and beyond chip select multiplexer pcb

palazzol, 2022-11-05:
board to replace the removed user selectability in rev e

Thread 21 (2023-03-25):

rev e operate in plain rom mode fix

abzman, 2023-03-25:
Need to either remove arduino or hold it in reset, board fix to add another jumper

palazzol, 2023-03-25:
Fixed in software, will close when it is pushed

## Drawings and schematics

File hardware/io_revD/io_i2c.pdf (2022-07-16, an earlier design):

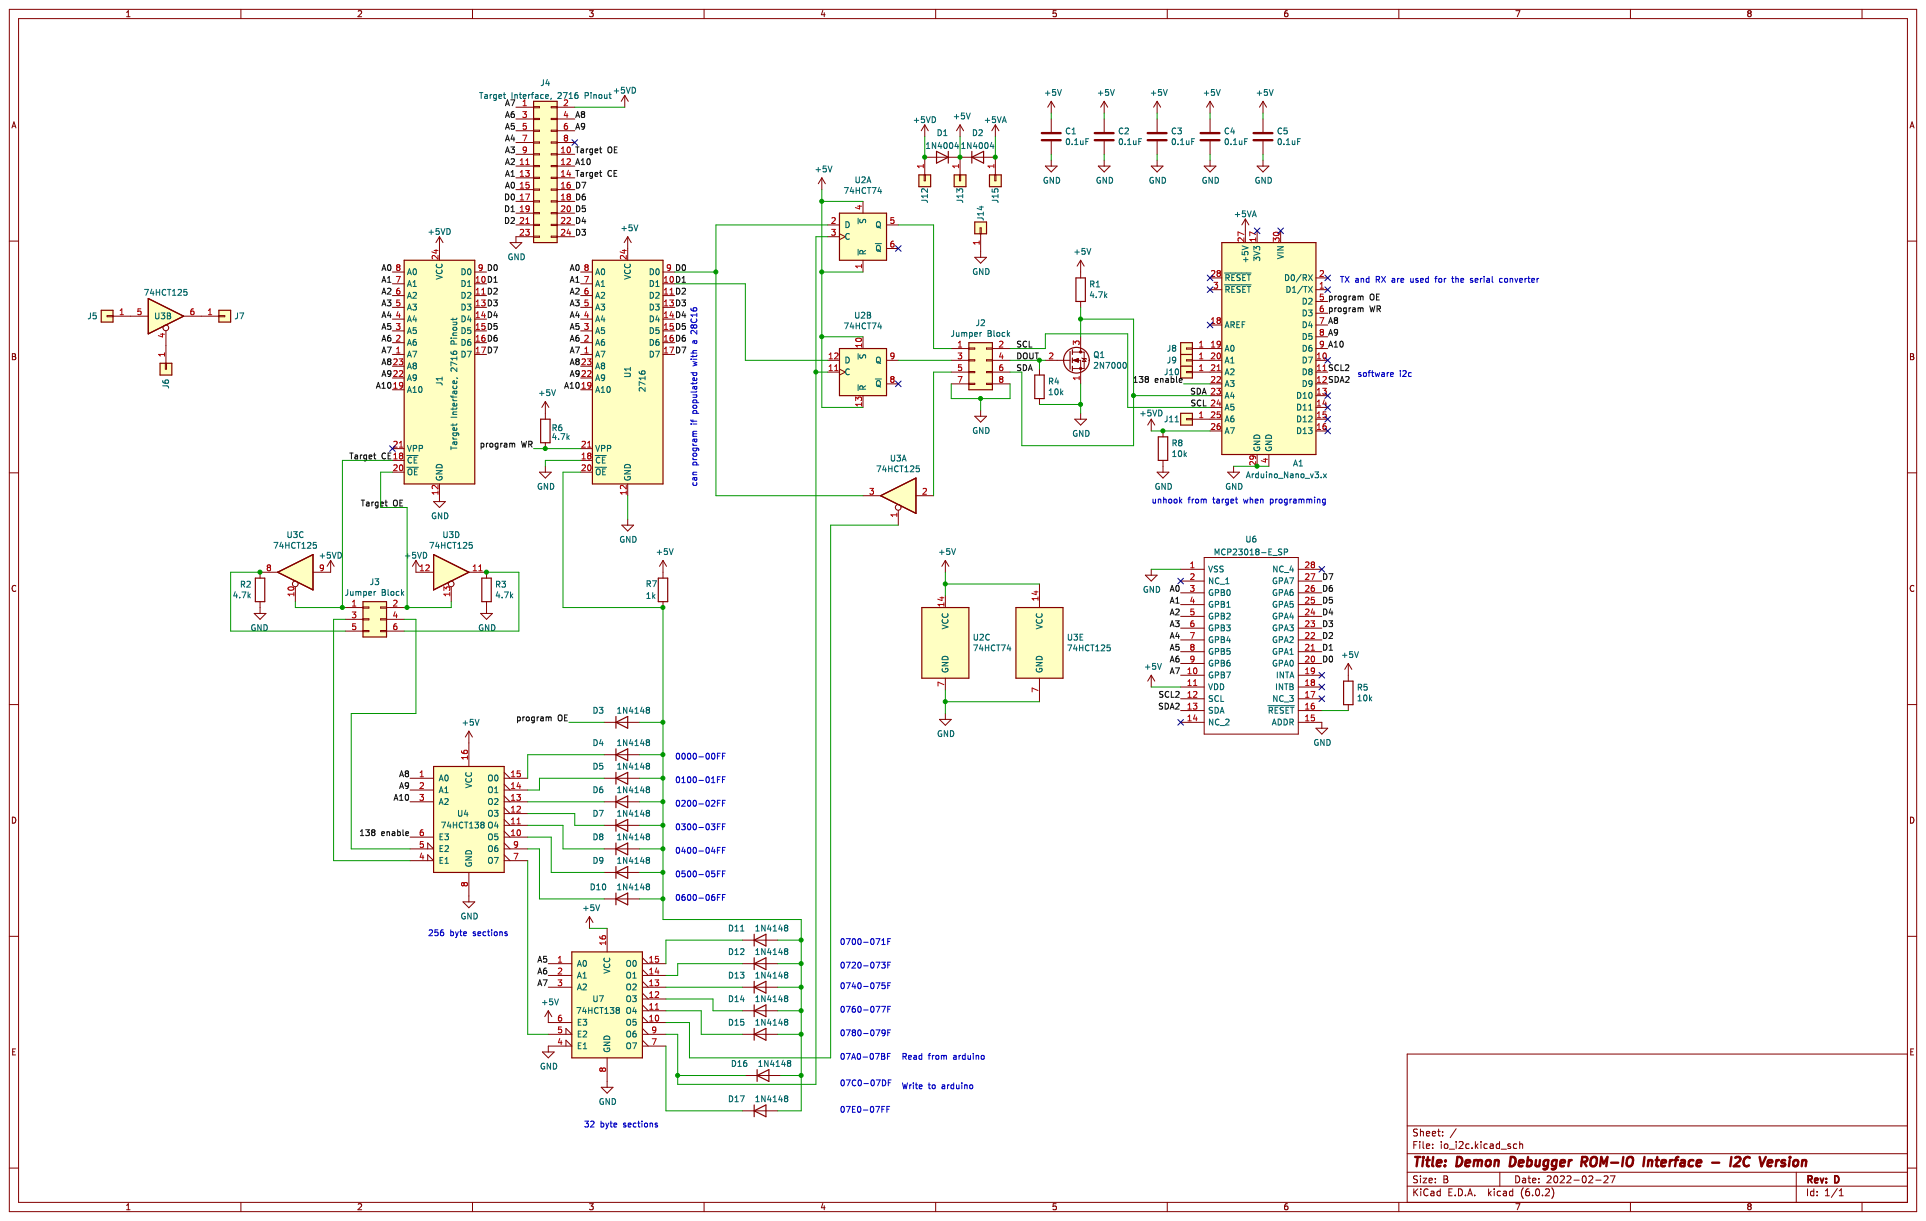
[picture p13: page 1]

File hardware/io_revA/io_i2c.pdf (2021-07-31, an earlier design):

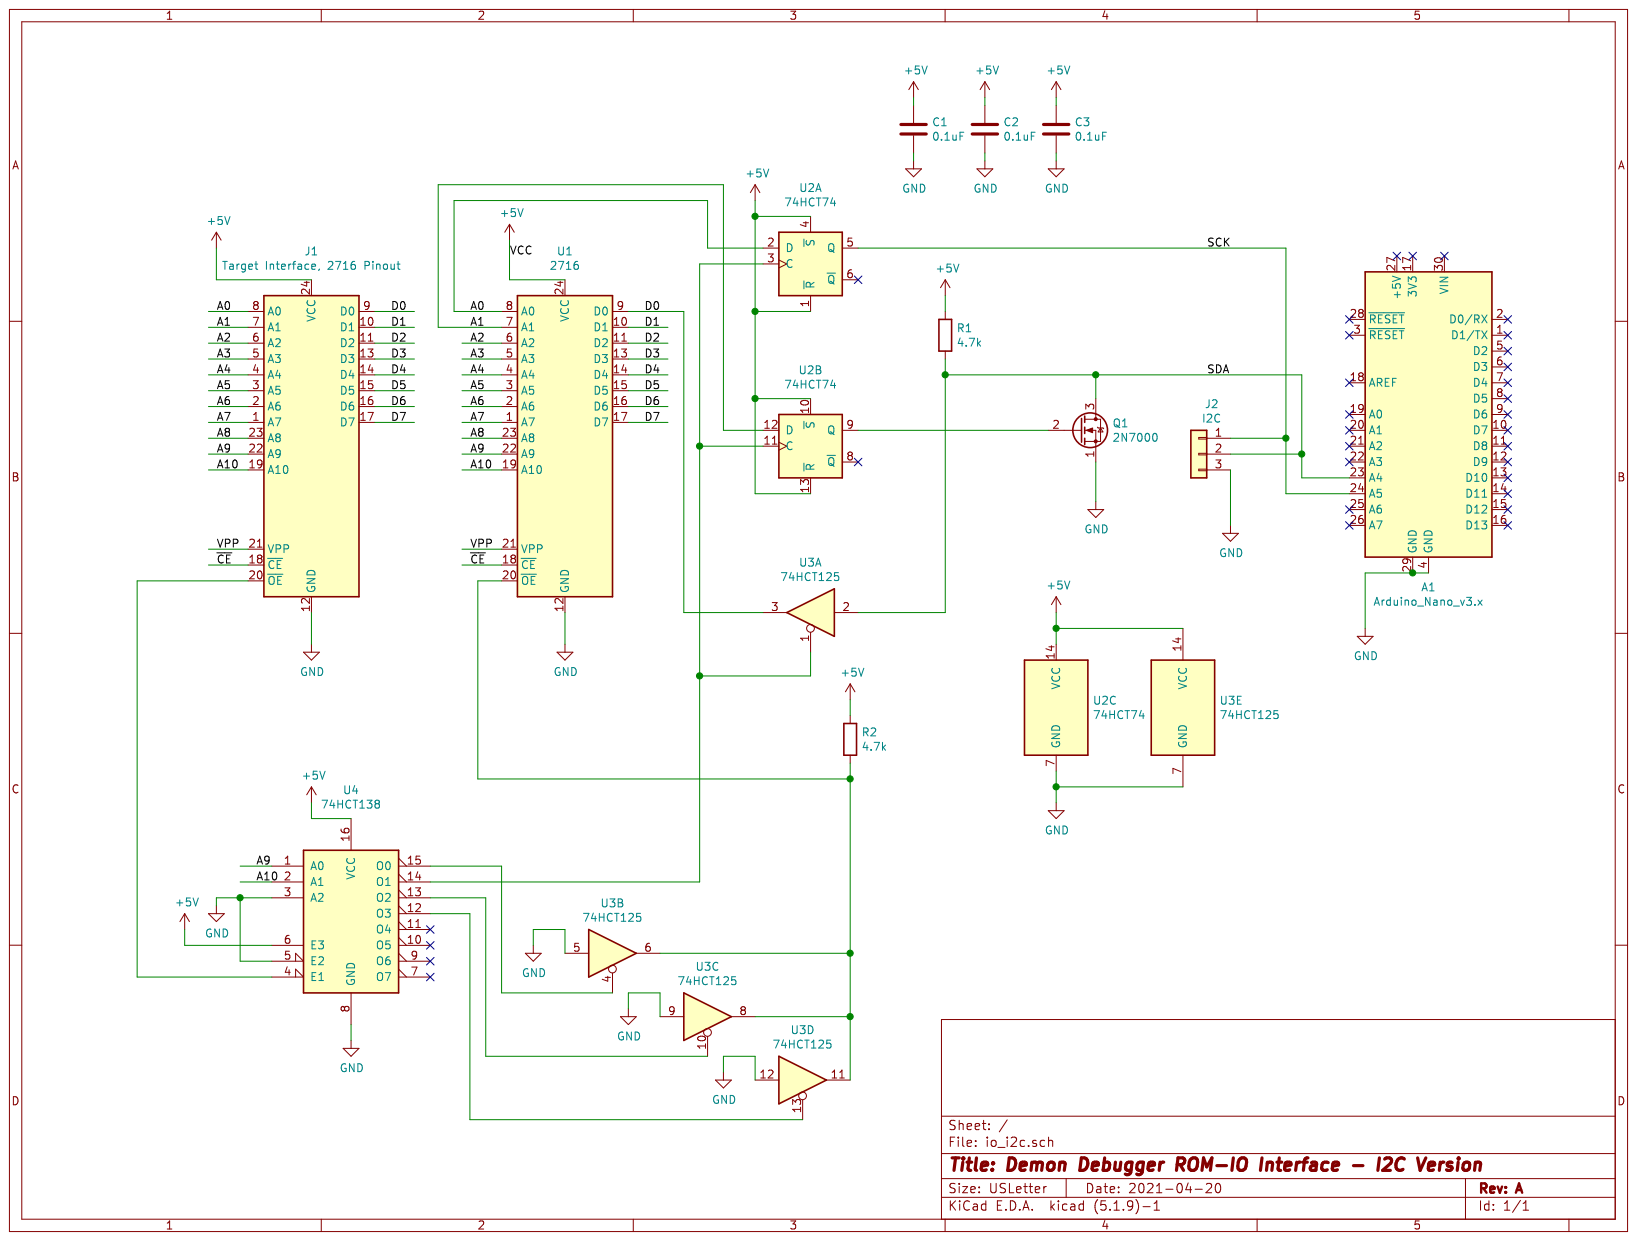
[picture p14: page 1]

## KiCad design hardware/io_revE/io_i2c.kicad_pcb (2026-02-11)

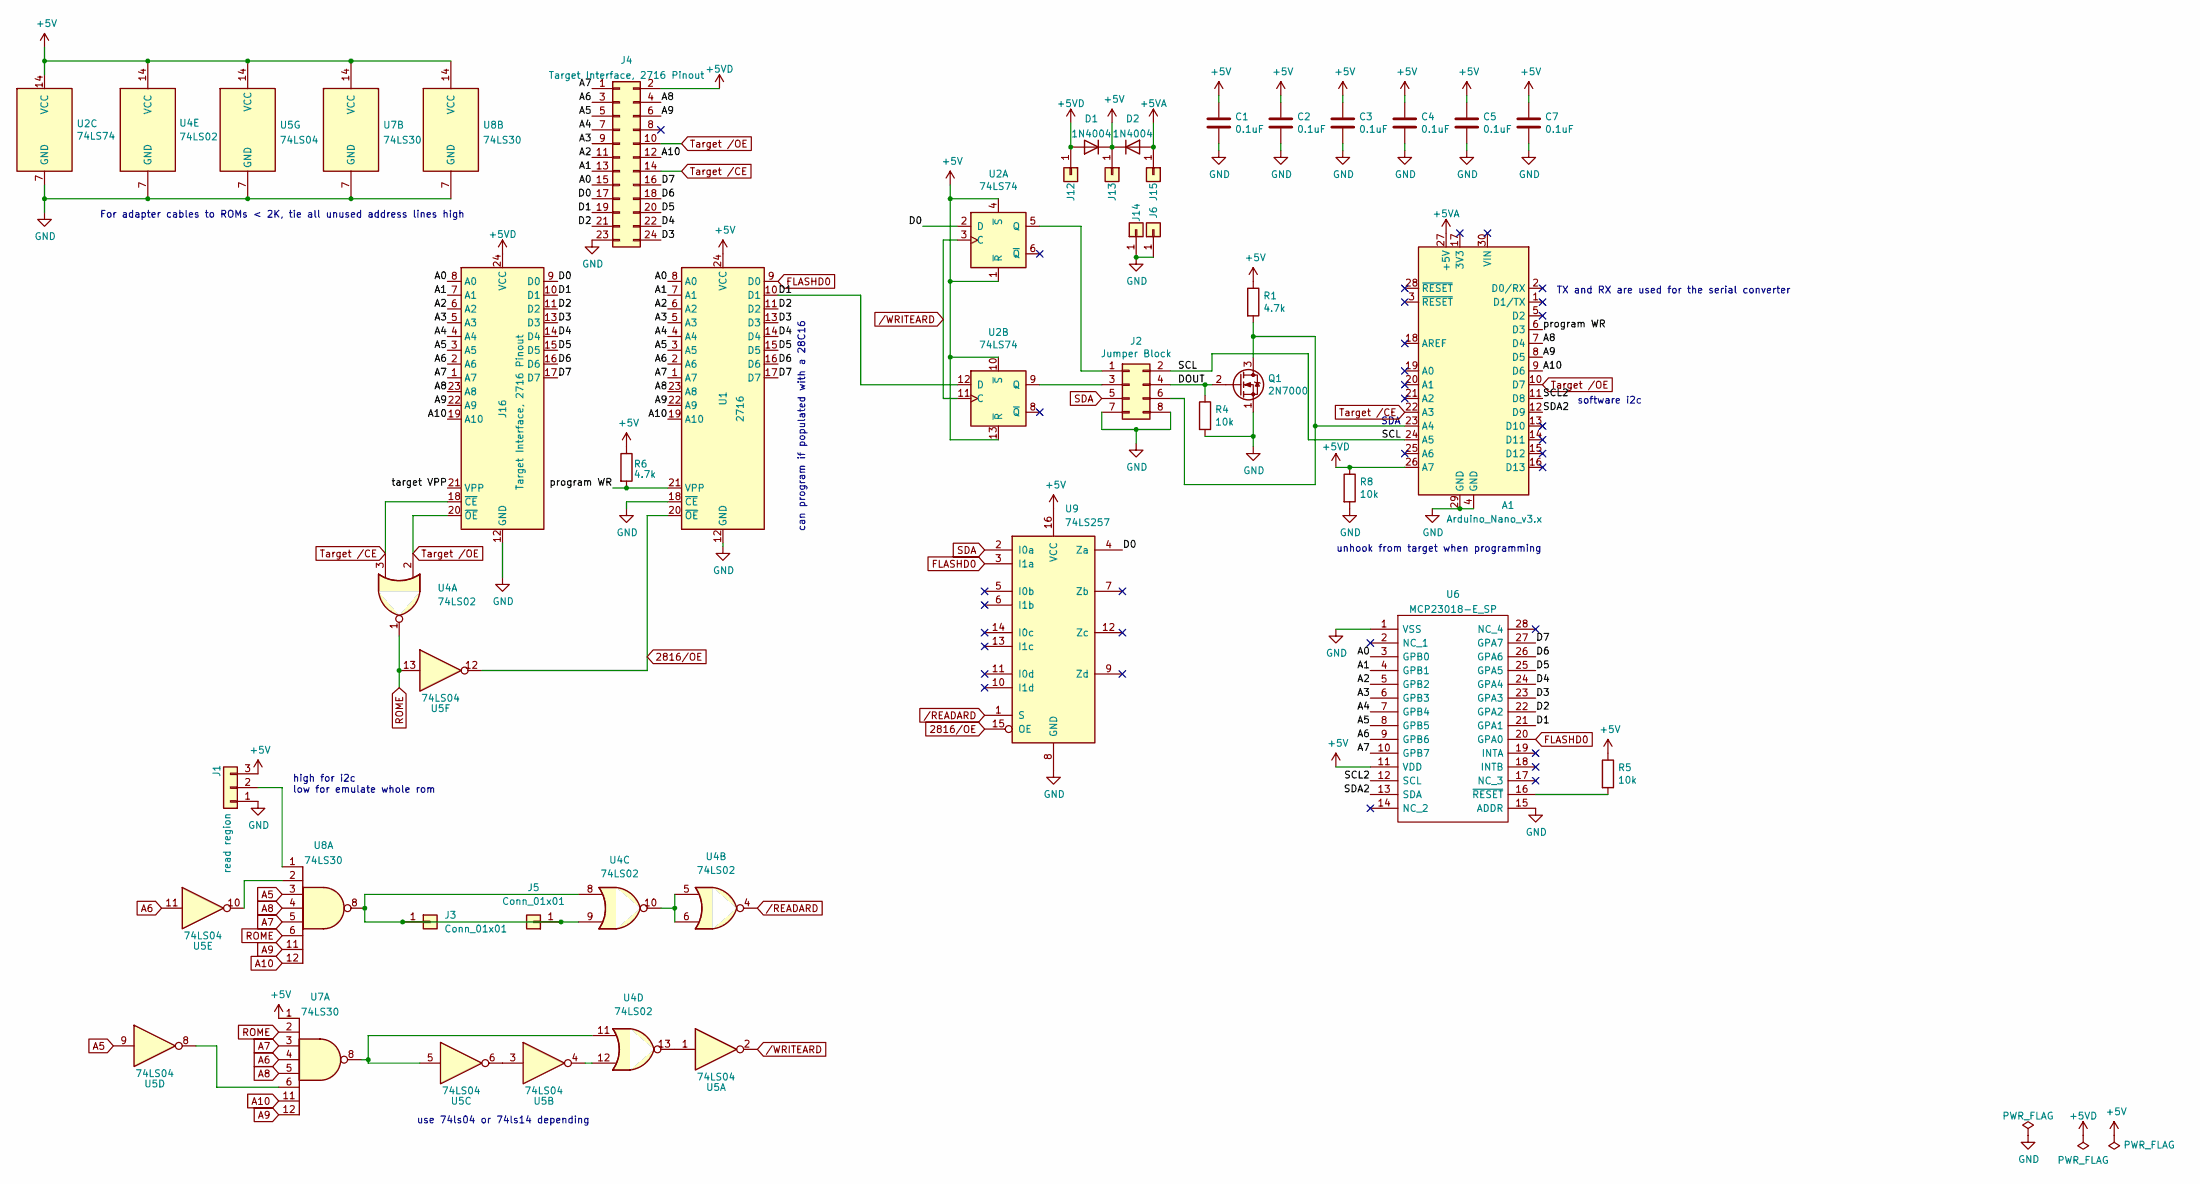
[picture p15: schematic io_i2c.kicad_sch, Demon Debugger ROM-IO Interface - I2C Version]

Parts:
A1: Arduino_Nano_v3.x; Arduino_Nano
C1, C2, C3, C4, C5, C7: 0.1uF; C_Axial_L3.8mm_D2.6mm_P7.50mm_Horizontal
D1, D2: 1N4004; D_DO-41_SOD81_P2.54mm_Vertical_AnodeUp
J1: read region; PinHeader_1x03_P2.54mm_Vertical
J2: Jumper Block; PinHeader_2x04_P2.54mm_Vertical
J3, J5, J6, J12, J13, J14, J15: Conn_01x01; PinHeader_1x01_P2.54mm_Vertical
J4: Target Interface, 2716 Pinout; PinHeader_2x12_P2.54mm_Vertical
J16: Target Interface, 2716 Pinout; DIP-24_W15.24mm_Socket
Q1: 2N7000; TO-92_Wide
R1, R6: 4.7k; R_Axial_DIN0207_L6.3mm_D2.5mm_P2.54mm_Vertical
R4, R5, R8: 10k; R_Axial_DIN0207_L6.3mm_D2.5mm_P2.54mm_Vertical
U1: 2716; DIP-24_W15.24mm_Socket
U2: 74LS74; DIP-14_W7.62mm
U4: 74LS02; DIP-14_W7.62mm
U5: 74LS04; DIP-14_W7.62mm
U6: MCP23018-E_SP; DIP-28_W7.62mm; Mouser Part Number 579-MCP23018-E/SP
U7, U8: 74LS30; DIP-14_W7.62mm
U9: 74LS257; DIP-16_W7.62mm

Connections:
2816/OE: U1.20 (~OE), U5.12, U9.15 (OE)
+5V: C1.1, C2.1, C3.1, C4.1, C5.1, C7.1, D1.1 (K), D2.1 (K), J1.3, J13.1, R1.1, R5.1, R6.1, U1.24 (VCC), U2.1 (~R), U2.4 (~S), U2.10 (~S), U2.13 (~R), U2.14 (VCC), U4.14 (VCC), U5.14 (VCC), U6.11 (VDD), U7.1, U7.14 (VCC), U8.14 (VCC), U9.16 (VCC)
+5VA: A1.27 (+5V), D2.2 (A), J15.1
+5VD: A1.26 (A7), D1.2 (A), J4.2, J12.1, J16.24 (VCC), R8.1
/A0: J4.15, J16.8 (A0), U1.8 (A0), U6.3 (GPB0)
/A1: J4.13, J16.7 (A1), U1.7 (A1), U6.4 (GPB1)
/A2: J4.11, J16.6 (A2), U1.6 (A2), U6.5 (GPB2)
/A3: J4.9, J16.5 (A3), U1.5 (A3), U6.6 (GPB3)
/A4: J4.7, J16.4 (A4), U1.4 (A4), U6.7 (GPB4)
/D0: J4.17, J16.9 (D0), U2.2 (D), U9.4 (Za)
/D1: J4.19, J16.10 (D1), U1.10 (D1), U2.12 (D), U6.21 (GPA1)
/D2: J4.21, J16.11 (D2), U1.11 (D2), U6.22 (GPA2)
/D3: J4.24, J16.13 (D3), U1.13 (D3), U6.23 (GPA3)
/D4: J4.22, J16.14 (D4), U1.14 (D4), U6.24 (GPA4)
/D5: J4.20, J16.15 (D5), U1.15 (D5), U6.25 (GPA5)
/D6: J4.18, J16.16 (D6), U1.16 (D6), U6.26 (GPA6)
/D7: J4.16, J16.17 (D7), U1.17 (D7), U6.27 (GPA7)
/DOUT: J2.4, Q1.2 (G), R4.1
/SCL: A1.24 (A5), J2.2
/SCL2: A1.11 (D8), U6.12 (SCL)
/SDA2: A1.12 (D9), U6.13 (SDA)
/program WR: A1.6 (D3), R6.2, U1.21 (VPP)
/target VPP: J16.21 (VPP)
A5: J4.5, J16.3 (A5), U1.3 (A5), U5.9, U6.8 (GPB5), U8.3
A6: J4.3, J16.2 (A6), U1.2 (A6), U5.11, U6.9 (GPB6), U7.4
A7: J4.1, J16.1 (A7), U1.1 (A7), U6.10 (GPB7), U7.3, U8.5
A8: A1.7 (D4), J4.4, J16.23 (A8), U1.23 (A8), U7.5, U8.4
A9: A1.8 (D5), J4.6, J16.22 (A9), U1.22 (A9), U7.12, U8.11
A10: A1.9 (D6), J4.12, J16.19 (A10), U1.19 (A10), U7.11, U8.12
FLASHD0: U1.9 (D0), U6.20 (GPA0), U9.3 (I1a)
GND: A1.4 (GND), A1.29 (GND), C1.2, C2.2, C3.2, C4.2, C5.2, C7.2, J1.1, J2.7, J2.8, J4.23, J6.1, J14.1, J16.12 (GND), Q1.1 (S), R4.2, R8.2, U1.12 (GND), U1.18 (~CE), U2.7 (GND), U4.7 (GND), U5.7 (GND), U6.1 (VSS), U6.15 (ADDR), U7.7 (GND), U8.7 (GND), U9.8 (GND)
unnamed: A1.23 (A4), J2.6, Q1.3 (D), R1.2
unnamed: J1.2, U8.1
unnamed: J2.1, U2.5 (Q)
unnamed: J2.3, U2.9 (Q)
unnamed: J3.1, J5.1, U4.8, U4.9, U8.8
unnamed: R5.2, U6.16 (~RESET)
unnamed: U4.5, U4.6, U4.10
unnamed: U4.11, U5.5, U7.8
unnamed: U4.12, U5.4
unnamed: U4.13, U5.1
unnamed: U5.3, U5.6
unnamed: U5.8, U7.6
unnamed: U5.10, U8.2
ROME: U4.1, U5.13, U7.2, U8.6
SDA: J2.5, U9.2 (I0a)
Target /CE: A1.22 (A3), J4.14, J16.18 (~CE), U4.3
Target /OE: A1.10 (D7), J4.10, J16.20 (~OE), U4.2
/READARD: U4.4, U9.1 (S)
/WRITEARD: U2.3 (C), U2.11 (C), U5.2

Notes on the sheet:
TX and RX are used for the serial converter
For adapter cables to ROMs < 2K, tie all unused address lines high
can program if populated with a 28C16
high for i2c low for emulate whole rom
use 74ls04 or 74ls14 depending
SDA
unhook from target when programming
software i2c

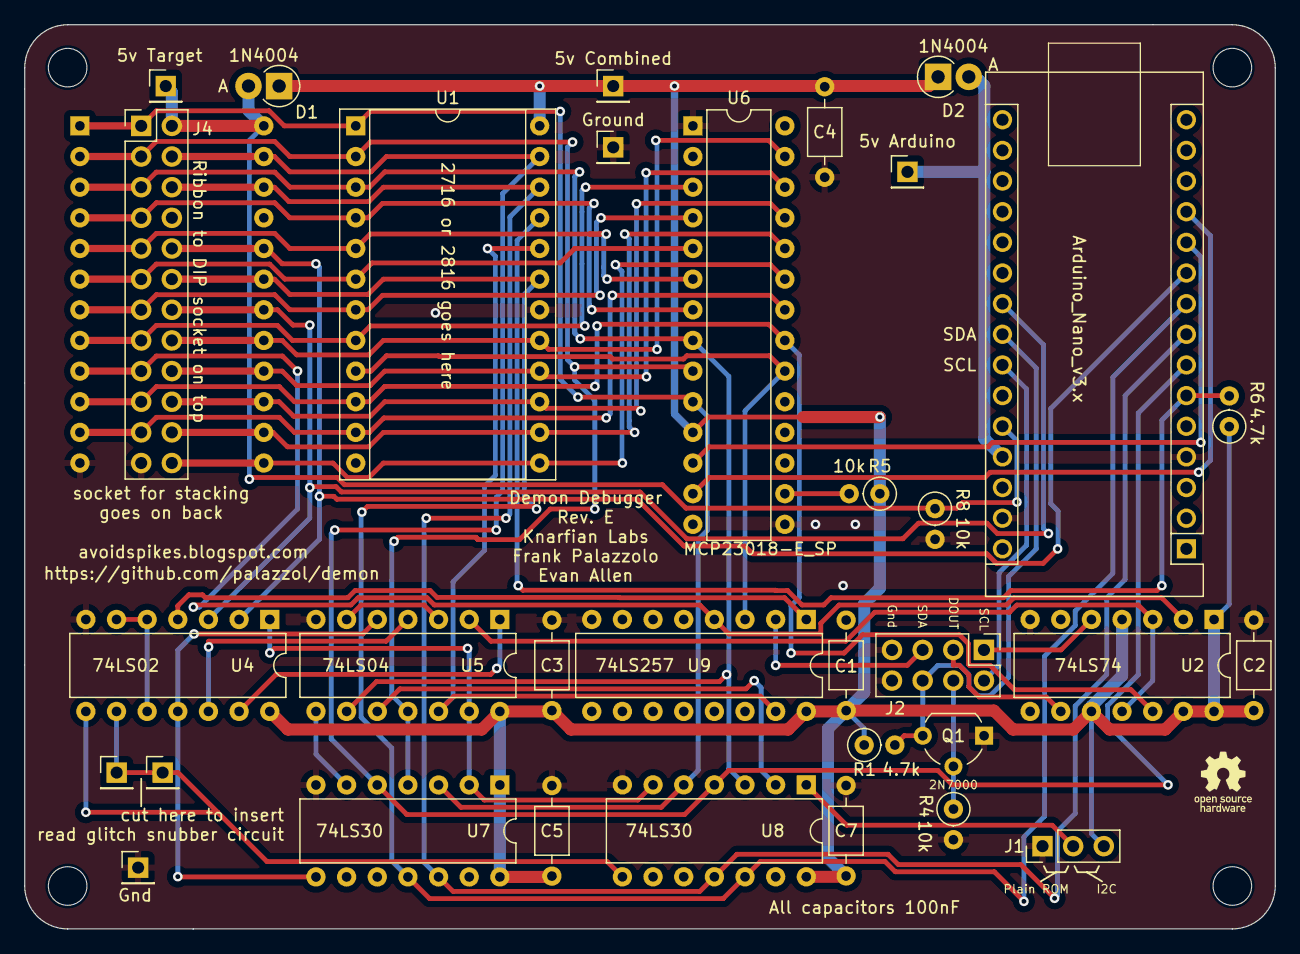
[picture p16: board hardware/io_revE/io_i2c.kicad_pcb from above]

Board: 2 copper layers, 103.6 x 74.9 mm, 34 parts (0 on the bottom side), 49 nets.

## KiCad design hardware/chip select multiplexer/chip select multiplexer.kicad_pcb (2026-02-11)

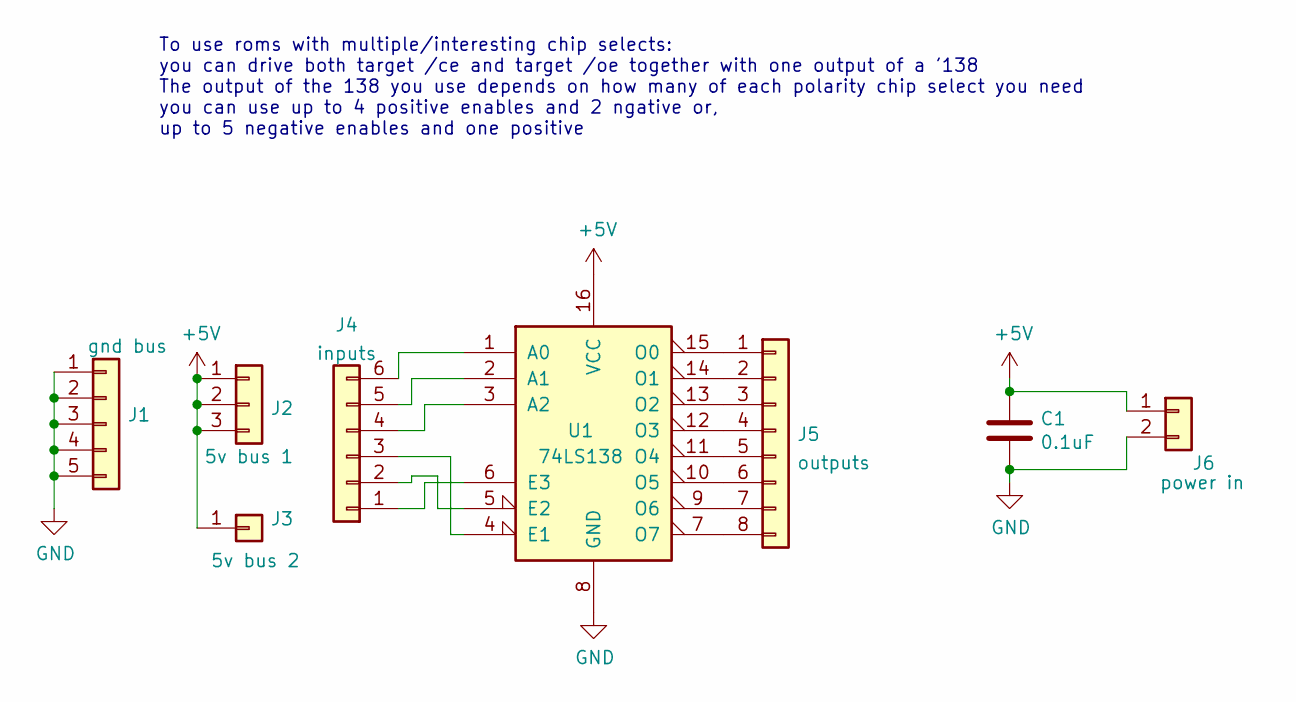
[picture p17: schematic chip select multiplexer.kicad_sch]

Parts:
C1: 0.1uF; C_Axial_L3.8mm_D2.6mm_P7.50mm_Horizontal
J1: gnd bus; PinHeader_1x05_P2.54mm_Vertical
J2: 5v bus 1; PinHeader_1x03_P2.54mm_Vertical
J3: 5v bus 2; PinHeader_1x01_P2.54mm_Vertical
J4: inputs; PinHeader_1x06_P2.54mm_Vertical
J5: outputs; PinHeader_1x08_P2.54mm_Vertical
J6: power in; PinHeader_1x02_P2.54mm_Vertical
U1: 74LS138; DIP-16_W7.62mm

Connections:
+5V: C1.1, J2.1, J2.2, J2.3, J3.1, J6.1, U1.16 (VCC)
GND: C1.2, J1.1, J1.2, J1.3, J1.4, J1.5, J6.2, U1.8 (GND)
unnamed: J4.1, U1.6 (E3)
unnamed: J4.2, U1.5 (E2)
unnamed: J4.3, U1.4 (E1)
unnamed: J4.4, U1.3 (A2)
unnamed: J4.5, U1.2 (A1)
unnamed: J4.6, U1.1 (A0)
unnamed: J5.1, U1.15 (O0)
unnamed: J5.2, U1.14 (O1)
unnamed: J5.3, U1.13 (O2)
unnamed: J5.4, U1.12 (O3)
unnamed: J5.5, U1.11 (O4)
unnamed: J5.6, U1.10 (O5)
unnamed: J5.7, U1.9 (O6)
unnamed: J5.8, U1.7 (O7)

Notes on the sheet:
To use roms with multiple/interesting chip selects: you can drive both target /ce and target /oe together with one output of a '138 The output of the 138 you use depends on how many of each polarity chip select you need you can use up to 4 positive enables and 2 ngative or, up to 5 negative enables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

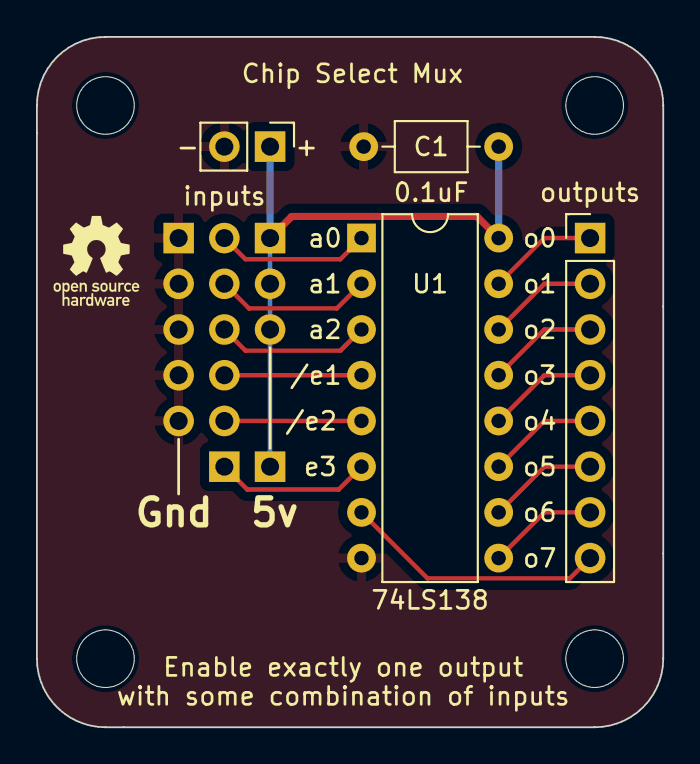
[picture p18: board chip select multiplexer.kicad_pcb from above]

Board: 2 copper layers, 34.8 x 38.4 mm, 8 parts (0 on the bottom side), 16 nets.

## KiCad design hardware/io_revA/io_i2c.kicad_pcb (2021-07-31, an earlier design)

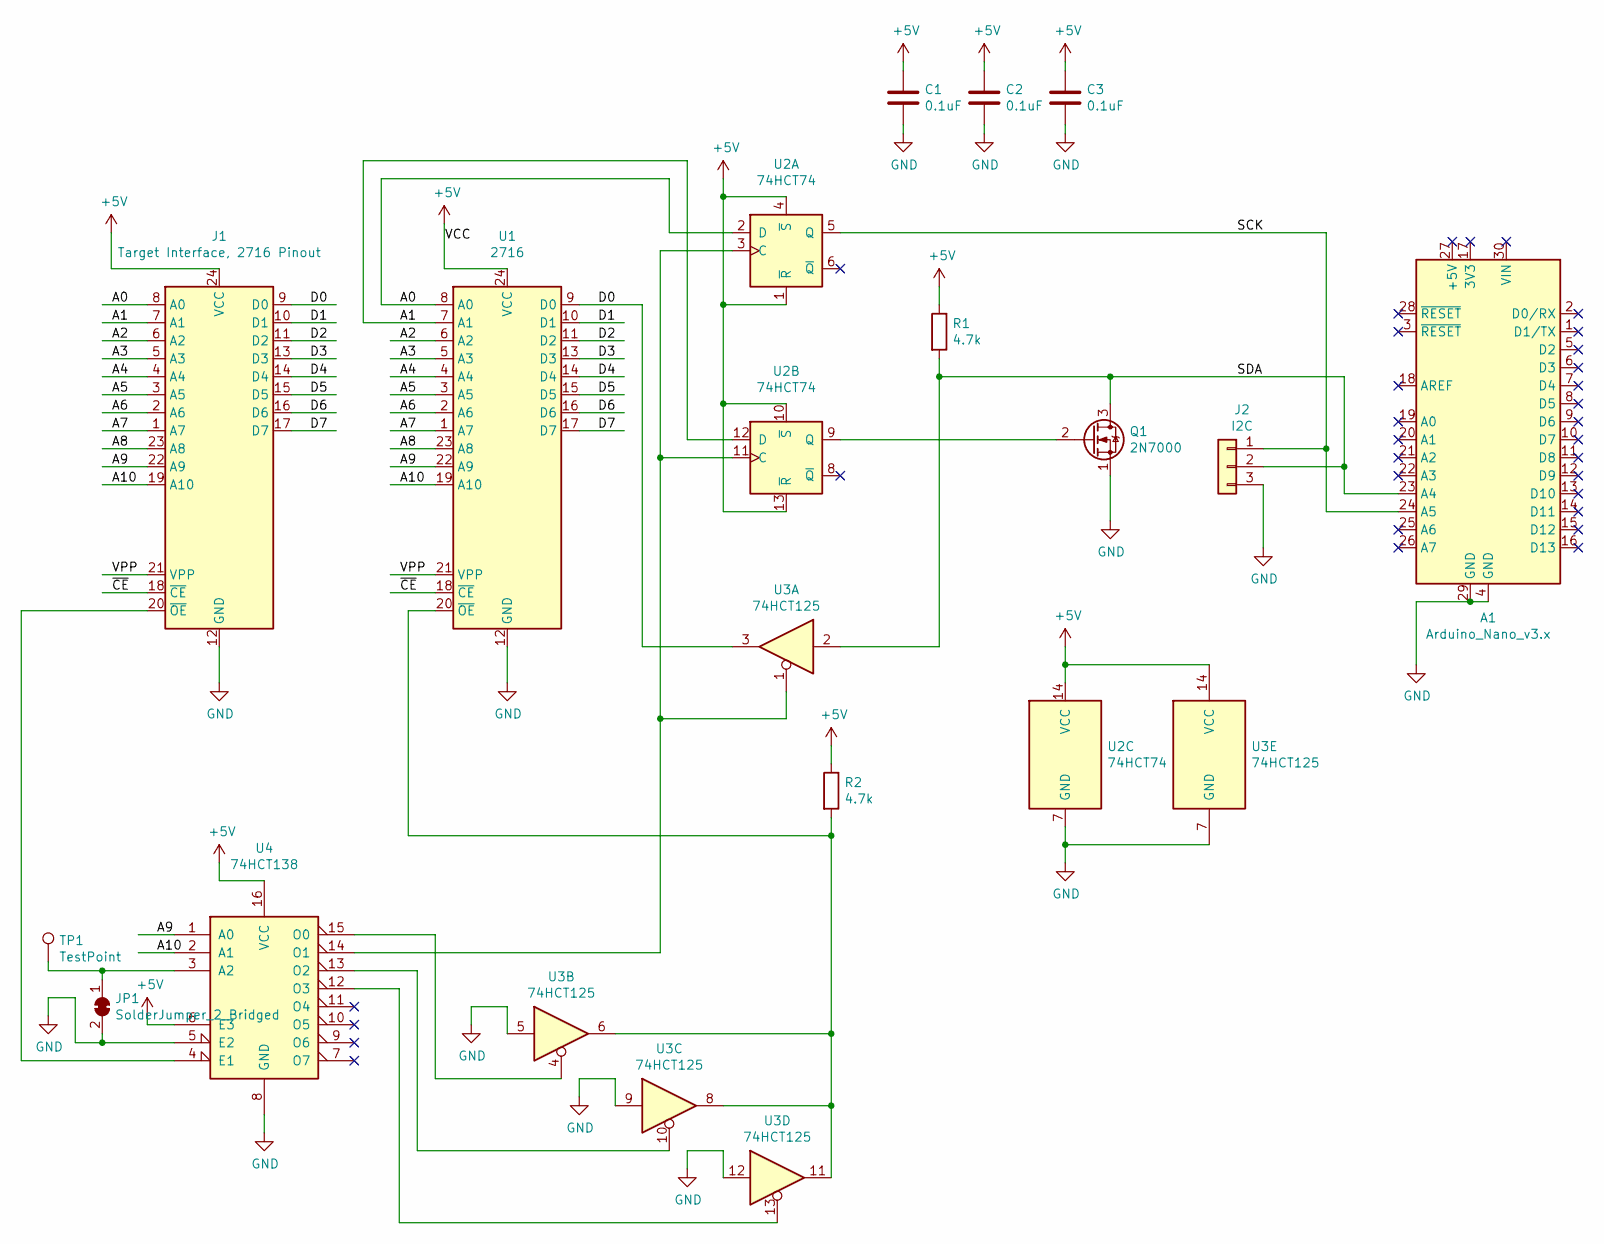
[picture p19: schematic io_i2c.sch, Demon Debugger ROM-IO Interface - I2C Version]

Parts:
A1: Arduino_Nano_v3.x; Arduino_Nano
C1, C2, C3: 0.1uF; C_Axial_L3.8mm_D2.6mm_P7.50mm_Horizontal
J1: Target Interface, 2716 Pinout; DIP-24_W15.24mm_Socket
J2: I2C; PinHeader_1x03_P2.54mm_Vertical
JP1: SolderJumper_2_Bridged; SolderJumper-2_P1.3mm_Bridged_RoundedPad1.0x1.5mm
Q1: 2N7000; TO-92_Inline
R1, R2: 4.7k; R_Axial_DIN0207_L6.3mm_D2.5mm_P10.16mm_Horizontal
TP1: TestPoint; TestPoint_THTPad_D1.5mm_Drill0.7mm
U1: 2716; DIP-24_W15.24mm_Socket
U2: 74HCT74; DIP-14_W7.62mm
U3: 74HCT125; DIP-14_W7.62mm
U4: 74HCT138; DIP-16_W7.62mm

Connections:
+5V: C1.1, C2.1, C3.1, J1.24 (VCC), R1.1, R2.1, U1.24 (VCC), U2.1 (~R), U2.4 (~S), U2.10 (~S), U2.13 (~R), U2.14 (VCC), U3.14 (VCC), U4.6 (E3), U4.16 (VCC)
/A0: J1.8 (A0), U1.8 (A0), U2.2 (D)
/A1: J1.7 (A1), U1.7 (A1), U2.12 (D)
/A2: J1.6 (A2), U1.6 (A2)
/A3: J1.5 (A3), U1.5 (A3)
/A4: J1.4 (A4), U1.4 (A4)
/A5: J1.3 (A5), U1.3 (A5)
/A6: J1.2 (A6), U1.2 (A6)
/A7: J1.1 (A7), U1.1 (A7)
/A8: J1.23 (A8), U1.23 (A8)
/A9: J1.22 (A9), U1.22 (A9), U4.1 (A0)
/A10: J1.19 (A10), U1.19 (A10), U4.2 (A1)
/D0: J1.9 (D0), U1.9 (D0), U3.3
/D1: J1.10 (D1), U1.10 (D1)
/D2: J1.11 (D2), U1.11 (D2)
/D3: J1.13 (D3), U1.13 (D3)
/D4: J1.14 (D4), U1.14 (D4)
/D5: J1.15 (D5), U1.15 (D5)
/D6: J1.16 (D6), U1.16 (D6)
/D7: J1.17 (D7), U1.17 (D7)
/SCK: A1.24 (A5), J2.1, U2.5 (Q)
/SDA: A1.23 (A4), J2.2, Q1.3 (D), R1.2, U3.2
/VPP: J1.21 (VPP), U1.21 (VPP)
/~CE: J1.18 (~CE), U1.18 (~CE)
GND: A1.4 (GND), A1.29 (GND), C1.2, C2.2, C3.2, J1.12 (GND), J2.3, JP1.2 (B), Q1.1 (S), U1.12 (GND), U2.7 (GND), U3.5, U3.7 (GND), U3.9, U3.12, U4.5 (E2), U4.8 (GND)
unnamed: J1.20 (~OE), U4.4 (E1)
unnamed: JP1.1 (A), TP1.1, U4.3 (A2)
unnamed: Q1.2 (G), U2.9 (Q)
unnamed: R2.2, U1.20 (~OE), U3.6, U3.8, U3.11
unnamed: U2.3 (C), U2.11 (C), U3.1, U4.14 (O1)
unnamed: U3.4, U4.15 (O0)
unnamed: U3.10, U4.13 (O2)
unnamed: U3.13, U4.12 (O3)

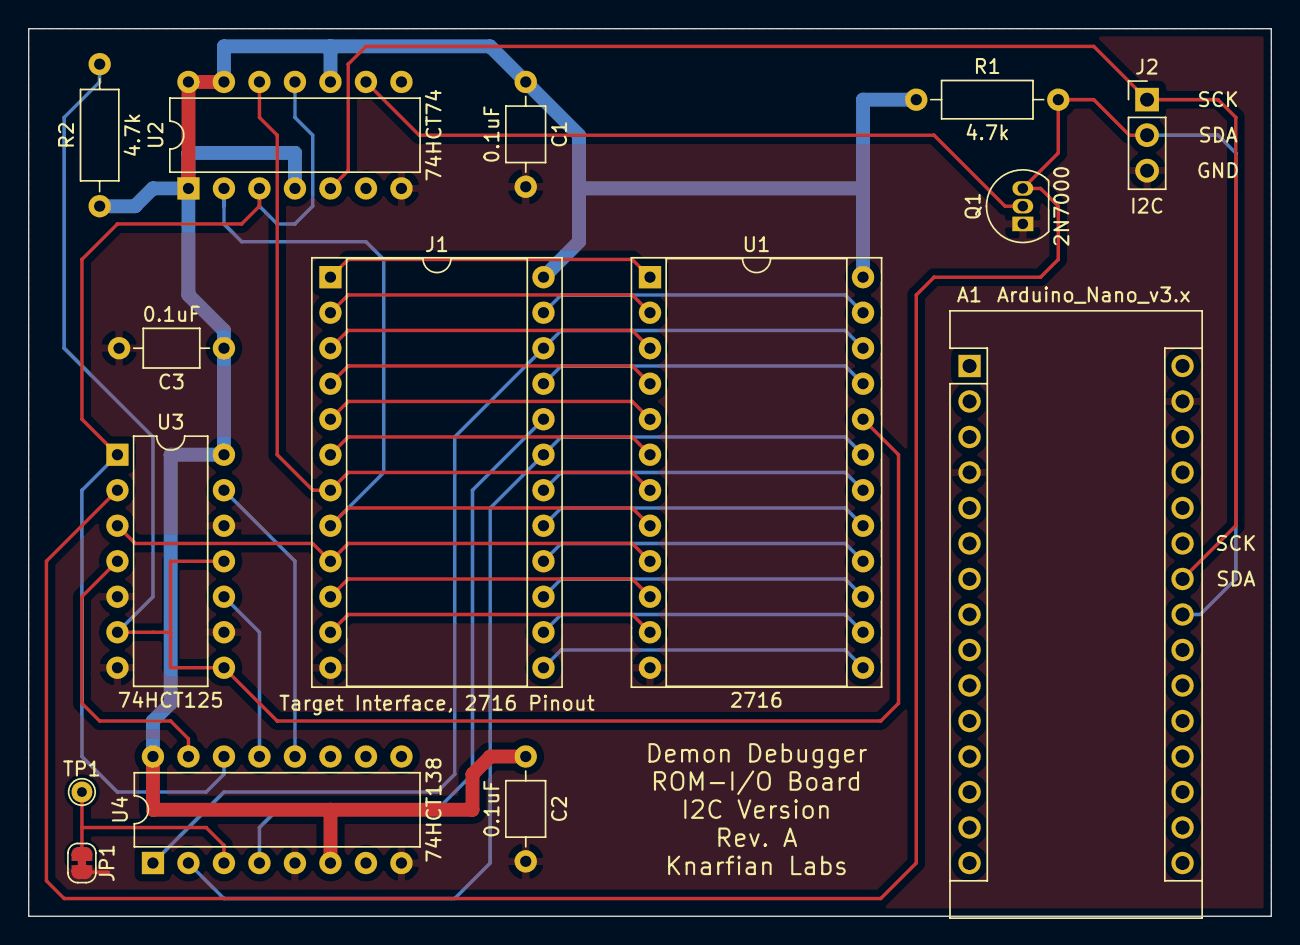
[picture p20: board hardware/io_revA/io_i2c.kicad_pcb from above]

Board: 2 copper layers, 88.9 x 63.5 mm, 15 parts (0 on the bottom side), 33 nets.

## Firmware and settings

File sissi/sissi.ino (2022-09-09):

#include "BitBang_I2C.h"
#include <Wire.h>

// SISSI - Simple I2C-Slave to Serial Interface
// by Frank Palazzolo

#define I2C_ADDRESS         0x08
#define I2C_ADDRESS_IOEXP   0x20

#define PIN_PROGRAM_nOE (2)
#define PIN_PROGRAM_WR  (3)
#define PIN_A8          (4)
#define PIN_A9          (5)
#define PIN_A10         (6)

#define PIN_IO_SCL      (8)
#define PIN_IO_SDA      (9)
#define PIN_138_ENABLE  (A3)
#define PIN_TARGET_PWR  (A7)

#define wr_high_fast() PORTD |= 0x08
#define wr_low_fast()  PORTD &= 0xf7

// Unused
#define PIN_NOBYPASS    (A0)
#define PIN_BYPASS      (A1)
#define PIN_NO_RC       (A2)

const char hex[16]="0123456789ABCDEF";

BBI2C bbi2c;

void setup() {
  // Disable Write!
  digitalWrite(PIN_PROGRAM_WR, HIGH);
  pinMode(PIN_PROGRAM_WR, OUTPUT);

  pinMode(PIN_PROGRAM_nOE, INPUT);
  pinMode(PIN_A8, INPUT);
  pinMode(PIN_A9, INPUT);
  pinMode(PIN_A10, INPUT);
  pinMode(PIN_IO_SCL, INPUT_PULLUP);
  pinMode(PIN_IO_SDA, INPUT_PULLUP);
  pinMode(PIN_TARGET_PWR, INPUT);

  pinMode(PIN_138_ENABLE, OUTPUT);
  digitalWrite(PIN_138_ENABLE, HIGH);

  pinMode(LED_BUILTIN, OUTPUT);
  digitalWrite(LED_BUILTIN, LOW);
  
  Serial.begin(250000);

  memset(&bbi2c, 0, sizeof(bbi2c));
  bbi2c.bWire = 0; // use bit banging
  bbi2c.iSDA = PIN_IO_SDA;
  bbi2c.iSCL = PIN_IO_SCL;
  I2CInit(&bbi2c, 100000L);
  delay(100);

  // Interactive mode, I2C slave
  Wire.begin(I2C_ADDRESS);    // join i2c bus with address
  Wire.onRequest(requestEvent); // register event
  Wire.onReceive(receiveEvent); // register event
}

const byte idle[4] = { 0x2E, 0x2E, 0x2E, 0x2E };
byte xmit_buffer[4] = { 0x2E, 0x2E, 0x2E, 0x2E };

int i2c_led_counter = 0;

void DoDownload()
{
  int v = analogRead(PIN_TARGET_PWR);
  if (v > 100) {
    Serial.println(":00000001FF");
    return;
  }

  // Disable Address Decoding
  digitalWrite(PIN_138_ENABLE, LOW);
  
  //Serial.println(I2CTest(&bbi2c, 0x20));

  // extra address pins driven
  pinMode(PIN_A8, OUTPUT);
  pinMode(PIN_A9, OUTPUT);
  pinMode(PIN_A10, OUTPUT);
  // data bus driven
  pinMode(PIN_PROGRAM_nOE, OUTPUT);
  digitalWrite(PIN_PROGRAM_nOE, LOW);
  
  uint8_t c[2] = { 0x01, 0x00 }; // enable address bus
  I2CWrite(&bbi2c, I2C_ADDRESS_IOEXP, &c[0], 2);
  uint8_t c1[2] = { 0x0d, 0xff }; // enable address bus pull ups
  I2CWrite(&bbi2c, I2C_ADDRESS_IOEXP, &c1[0], 2);
  uint8_t checksum = 0;
  for(int address=0;address<0x800;address++)
  {
    uint8_t c[2] = { 0x15, 0x00 }; // write to address bus
    uint8_t d;
    digitalWrite(PIN_A8, (address>>8)&1);
    digitalWrite(PIN_A9, (address>>9)&1);
    digitalWrite(PIN_A10, (address>>10)&1);
    c[1] = address&0xff;
    I2CWrite(&bbi2c, I2C_ADDRESS_IOEXP, &c[0], 2);
    delay(1);
    I2CReadRegister(&bbi2c, 0x20, 0x12, &d, 1); // read the data bus
    if (address % 16 == 0)
    {
      checksum = 0;
      Serial.print(":10");
      checksum += 0x10;
      Serial.print("0");
      Serial.print(hex[(address>>8)&0x0f]);
      Serial.print(hex[(address>>4)&0x0f]);
      Serial.print(hex[address&0x0f]);
      checksum += ((address>>8)&0xff);
      checksum += (address&0xff);
      Serial.print("00");
      checksum += 0x00;
    }
    Serial.write(hex[(d>>4)&0x0f]);
    Serial.write(hex[(d&0x0f)]);
    checksum += d;
    if (address % 16 == 15)
    {
      checksum = (0xff - checksum) + 1;
      Serial.write(hex[(checksum>>4)&0x0f]);
      Serial.write(hex[(checksum&0x0f)]);
      Serial.println();
    }    
  }
  Serial.println(":00000001FF");
  
  uint8_t c2[2] = { 0x0d, 0x00 }; // disable address bus pull ups
  I2CWrite(&bbi2c, I2C_ADDRESS_IOEXP, &c2[0], 2);
  uint8_t c3[2] = { 0x01, 0xff }; // disable address bus
  I2CWrite(&bbi2c, I2C_ADDRESS_IOEXP, &c3[0], 2);

  // data bus undriven
  pinMode(PIN_PROGRAM_nOE, INPUT);

  // extra address bits undriven
  pinMode(PIN_A8, INPUT);
  pinMode(PIN_A9, INPUT);
  pinMode(PIN_A10, INPUT);

  // Enable Address Decoding
  digitalWrite(PIN_138_ENABLE, HIGH);
}

uint8_t DecodeNibble(uint8_t c)
{
  if ((c >= '0') && (c <= '9')) {
    return c - '0';
  } else if ((c >= 'A') && (c <= 'F')) {
    return c - 'A' + 10;
  } else if ((c >= 'a') && (c <= 'f')) {
    return c - 'a' + 10;
  } else
    return 0x00;  //?
}

uint8_t DecodeByte(uint8_t ch, uint8_t cl)
{
  return (DecodeNibble(ch)<<4) | DecodeNibble(cl);
}

// return - 0=keep_going, 1=success, 2=fail
int ProcessUploadLine(char line_buffer[], int buf_length)
{
  uint8_t data_length = 0;
  uint8_t data_type = 0;
  uint8_t checksum = 0;
  uint8_t checksum2 = 0;
  uint8_t ah,al;
  int address;
    if (buf_length < 11)
      return 2;
    if (line_buffer[0] != ':')
      return 3;
    data_length = DecodeByte(line_buffer[1],line_buffer[2]);
    if (buf_length < (11+2*data_length))
      return 4;
    checksum = data_length;
    ah = DecodeByte(line_buffer[3],line_buffer[4]);
    checksum += ah;
    al = DecodeByte(line_buffer[5],line_buffer[6]);
    checksum += al;
    address = ah;
    address <<= 8;
    address |= al;
    data_type = DecodeByte(line_buffer[7],line_buffer[8]);
    //Serial.print((char)line_buffer[7]);
    //Serial.print((char)line_buffer[8]);
    //Serial.println(data_type,HEX);
    //Serial.print("data_type=");
    //Serial.println(data_type,HEX);
    checksum += data_type;
    if (address+data_length > 0x800)
      return 5;
    if (data_type > 1)
      return 6;
    int j=0;
    for(j=0;j<data_length;j++)
    {
      uint8_t data = DecodeByte(line_buffer[9+2*j],line_buffer[10+2*j]);
      checksum += data;
    }
    checksum = (checksum ^ 0xff) + 1;
    checksum2 = DecodeByte(line_buffer[9+2*j],line_buffer[10+2*j]);
    //Serial.print("checksum=");
    //Serial.println(checksum,HEX);
    //Serial.print("checksum2=");
    //Serial.println(checksum2,HEX);
    if (checksum != checksum2)
      return 7;
    if (data_type == 0) {
      for(int j=0;j<data_length;j++)
      {
        uint8_t data = DecodeByte(line_buffer[9+2*j],line_buffer[10+2*j]);
        digitalWrite(PIN_A8, (address>>8)&1);
        digitalWrite(PIN_A9, (address>>9)&1);
        digitalWrite(PIN_A10, (address>>10)&1);
        uint8_t c[2] = { 0x15, 0x00 }; // write to address bus
        c[1] = address&0xff;
        I2CWrite(&bbi2c, I2C_ADDRESS_IOEXP, &c[0], 2);
        uint8_t d[2] = { 0x14, 0x00 }; // write to data bus
        d[1] = data;
        I2CWrite(&bbi2c, I2C_ADDRESS_IOEXP, &d[0], 2);
        delay(1);
        // data write
        noInterrupts();
#ifdef FAST
        wr_low_fast();
        //__builtin_avr_delay_cycles(8);  // 0.5 us
        delayMicroseconds(500);
        wr_high_fast();
#endif
        digitalWrite(PIN_PROGRAM_WR, LOW);
        delayMicroseconds(1);
        digitalWrite(PIN_PROGRAM_WR, HIGH);
        interrupts();
        delay(5);
        //Serial.print(address,HEX);
        //Serial.print(" ");
        //Serial.println(data,HEX);
        address++;
      }
      // data not ready to write
      digitalWrite(PIN_PROGRAM_WR, HIGH);
    }
    if (data_type == 1)
    {
      return 1;
    }      
  return 0;
}

void DoUpload()
{
  int v = analogRead(PIN_TARGET_PWR);
  if (v > 100) {
    Serial.println(":00000001FF");
    return;
  }

  // Disable Address Decoding
  digitalWrite(PIN_138_ENABLE, LOW);
  
  //Serial.println(I2CTest(&bbi2c, 0x20));

  // extra address pins enabled
  pinMode(PIN_A8, OUTPUT);
  pinMode(PIN_A9, OUTPUT);
  pinMode(PIN_A10, OUTPUT);

  uint8_t c[2] = { 0x01, 0x00 }; // enable address bus
  I2CWrite(&bbi2c, I2C_ADDRESS_IOEXP, &c[0], 2);
  uint8_t c1[2] = { 0x0d, 0xff }; // enable address bus pull ups
  I2CWrite(&bbi2c, I2C_ADDRESS_IOEXP, &c1[0], 2);

  uint8_t d[2] = { 0x00, 0x00 }; // enable data bus
  I2CWrite(&bbi2c, I2C_ADDRESS_IOEXP, &d[0], 2);
  uint8_t d1[2] = { 0x0c, 0xff }; // enable data bus pull ups
  I2CWrite(&bbi2c, I2C_ADDRESS_IOEXP, &d1[0], 2);
  
  // state - 0=keep_going, 1=success, >1=fail
  int state = 0;
  uint8_t line_buffer[256];
  uint8_t index = 0;
  uint8_t dd;
  while (state == 0)
  {
    if (Serial.available()) {
      dd = Serial.read();
      if ((dd == '\n') || (dd == '\r')) {
        if (index > 0)
        {
          state = ProcessUploadLine(line_buffer, index);
          if (state == 0)
          {
            Serial.println("*");  // ACK, more please
            //Serial.println(state);
          }
          index = 0;
        }
      }
      else if (index < 256)
      {
        line_buffer[index] = dd;
        index++;
      }
    }
  }
  //Serial.print("Upload Exit: code=");
  //Serial.println(state,HEX);

  uint8_t d2[2] = { 0x0c, 0x00 }; // disable data bus pull ups
  I2CWrite(&bbi2c, I2C_ADDRESS_IOEXP, &d2[0], 2);
  uint8_t d3[2] = { 0x00, 0xff }; // disable data bus
  I2CWrite(&bbi2c, I2C_ADDRESS_IOEXP, &d3[0], 2);
  
  uint8_t c2[2] = { 0x0d, 0x00 }; // disable address bus pull ups
  I2CWrite(&bbi2c, I2C_ADDRESS_IOEXP, &c2[0], 2);
  uint8_t c3[2] = { 0x01, 0xff }; // disable address bus
  I2CWrite(&bbi2c, I2C_ADDRESS_IOEXP, &c3[0], 2);

  digitalWrite(PIN_PROGRAM_WR, HIGH);

  // extra address pins undriven
  pinMode(PIN_A8, INPUT);
  pinMode(PIN_A9, INPUT);
  pinMode(PIN_A10, INPUT);

  // Enable Address Decoding
  digitalWrite(PIN_138_ENABLE, HIGH);
}

void loop() {
  if (i2c_led_counter == 0)
      digitalWrite(LED_BUILTIN, LOW);
  else {
      digitalWrite(LED_BUILTIN, HIGH);
      i2c_led_counter--;
  }
}

// function that executes whenever data is requested by master
// this function is registered as an event, see setup()
void requestEvent() {
  i2c_led_counter = 1000;  // This keeps the I2C LED on long enough to be seen
  Wire.write(xmit_buffer,4);
  memcpy(xmit_buffer,idle,4);
}

// function that executes whenever data is received from master
// this function is registered as an event, see setup()
void receiveEvent(int how_many) {
   while (Wire.available()) {
    byte b = Wire.read();     // receive byte as a character
    //Serial.write(b);
    Serial.write(hex[(b>>4)&0x0f]);
    Serial.write(hex[(b&0x0f)]);
    Serial.write('\n');
   }
}

void DoExternalFunction(uint8_t c)
{
  switch(c) {
    case 'D':
      DoDownload();
    break;
    case 'U':
      DoUpload();
    break;
    default:
       Serial.println("I");  // return to interactive mode
    break;
  }
}

bool got_nibble = false;
char inputString[4];
int inputStringIndex = 0;

// RWOIC - X
void serialEvent() {
  while (Serial.available()) {
    byte c = (byte)Serial.read();
    if ((c == '\n') || (c == '\r')) {
      if (inputStringIndex > 0) {
        if (inputString[0] == 'X')
        {
          if (inputStringIndex > 1)
          {
            DoExternalFunction(inputString[1]);
          }
          inputStringIndex = 0;
          got_nibble = false;
        }
        else
          memcpy(xmit_buffer,inputString,4);
       }
      inputStringIndex = 0;
      got_nibble = false;
    } else if (inputStringIndex == 0) {
        inputString[inputStringIndex] = c;
        inputStringIndex++;
    } else if (inputStringIndex < 4) {
      if (inputString[0] == 'X')
      {
        inputString[inputStringIndex] = c;
        inputStringIndex++;
      }
      else
      {
        byte n = 0;
        if ((c >= '0') && (c <= '9')) {
          n = c - '0';
        } else if ((c >= 'A') && (c <= 'F')) {
          n = c - 'A' + 10;
        } else if ((c >= 'a') && (c <= 'f')) {
          n = c - 'a' + 10;
        }
        if (!got_nibble) {
          inputString[inputStringIndex] = n*16;
          got_nibble = true;
        } else {
          inputString[inputStringIndex] += n;
          got_nibble = false;
          inputStringIndex++;
        }
      }
    }
  }
}

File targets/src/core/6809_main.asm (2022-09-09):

;;;;;;;;;;;;;;;;;;;;;;;;;;;;;;;;;;;;;;;;;;;;;;;;;;;;;;;;;;;;;;;;;;;;;;;;;;;
; RAM Variables 
;;;;;;;;;;;;;;;;;;;;;;;;;;;;;;;;;;;;;;;;;;;;;;;;;;;;;;;;;;;;;;;;;;;;;;;;;;;

OUTBUF  .equ    RAMSTRT         ;buffer for output states
BREG    .equ    RAMSTRT+0x01    ;general purpose
C       .equ    RAMSTRT+0x02    ;general purpose
CMDBUF0 .equ    RAMSTRT+0x03    ;command buffer
CMDBUF1 .equ    RAMSTRT+0x04    ;command buffer
CMDBUF2 .equ    RAMSTRT+0x05    ;command buffer
CMDBUF3 .equ    RAMSTRT+0x06    ;command buffer

; I2C ADDRESSING
I2CRADR .equ    0x11        ; I2C read address  - I2C address 0x08
I2CWADR .equ    0x10        ; I2C write address - I2C address 0x08

INIT:
        ldaa    #0x00
        staa    OUTBUF

; Main routine
MAIN:
        jsr     EVERY
        jsr     POLL
        bcs     MAIN
        ldaa    #BIGDEL>>8
        staa    BREG
        ldaa    #BIGDEL%256
        staa    C
MLOOP:
        ldaa    C
        beq     DECBOTH
        dec     C
        jmp     MLOOP
DECBOTH:
        ldaa    BREG
        beq     MAIN
        dec     C
        dec     BREG
        jmp     MLOOP

; Delay for half a bit time
I2CDLY: rts             ; TBD - this is plenty?

; I2C Start Condition
I2CSTART:
        jsr    CLRSDA      
        jsr    CLRSCL
        rts

; I2C Stop Condition
; Uses HL
; Destroys A
I2CSTOP:
        jsr    CLRSDA
        jsr    SETSCL
        jsr    SETSDA
        rts
        
I2CRBIT:
        jsr     SETSDA
        jsr     SETSCL
        jsr     READSDA ; sets/clears carry flag
        rola            ; save carry flag here
        psha
        jsr     CLRSCL
        pula
        rora            ; restore carry flag here
        rts             ; carry flag still good here

I2CWBIT:
        bcc     DOCLR
        jsr     SETSDA
        jmp     AHEAD
DOCLR:
        jsr     CLRSDA
AHEAD:
        jsr     SETSCL
        jsr     CLRSCL
        rts
        
I2CWBYTE:
        ldab    #0x08   
ILOOP:
        rola                ; high bit into carry
        psha
        jsr     I2CWBIT
        pula
        decb
        bne     ILOOP
        jsr     I2CRBIT
        rts
        
I2CRBYTE:
        ldab    #0x08
        ldaa    #0x00
LOOP3:
        psha
        jsr     I2CRBIT     ; get bit in carry flag
        pula
        rola                ; rotate carry into bit0
        decb
        bne     LOOP3
        clc                 ; clear carry flag 
        psha             
        jsr     I2CWBIT
        pula
        rts

I2CRREQ:
        jsr     I2CSTART
        ldaa    #I2CRADR
        jsr     I2CWBYTE
        bcs     SKIP
        jsr     I2CRBYTE
        staa    CMDBUF0
        jsr     I2CRBYTE
        staa    CMDBUF1
        jsr     I2CRBYTE
        staa    CMDBUF2
        jsr     I2CRBYTE
        staa    CMDBUF3
        jsr     ENDI2C
        clc                 ; everything was ok
        rts
    
SKIP:                       ; If no device present, fake an idle response
        ldaa    #0x2e  ; '.'
        staa    CMDBUF0
        jsr     ENDI2C
        sec                 ; aborted return
        rts 

I2CSRESP:
        psha
        jsr     I2CSTART
        ldaa    #I2CWADR
        jsr     I2CWBYTE
        pula
        jsr     I2CWBYTE
ENDI2C:
        jsr     I2CSTOP
        rts

POLL:
        jsr     I2CRREQ
        bcs     ABORT
        ldaa    CMDBUF0
        cmpa    #0x52           ; 'R' - Read memory
        beq     MREAD
        cmpa    #0x57           ; 'W' - Write memory
        beq     MWRITE
        cmpa    #0x43           ; 'C' - Call subroutine
        beq     REMCALL
ABORT:
        clc                     ; dont request again right away
        rts

MREAD:
        jsr     LOADBC
        ldx     BREG
        ldaa    0,X
        jmp     SRESP
MWRITE:
        jsr     LOADBC
        ldaa    CMDBUF3
        ldx     BREG
        staa    0,X
        ldaa    #0x57   ;'W'
        jmp     SRESP
LOADBC:
        ldaa    CMDBUF1
        staa    BREG
        ldaa    CMDBUF2
        staa    C
        rts
        
SRESP:
        jsr    I2CSRESP
RHERE:
        sec                     ; request again right away
        rts
REMCALL:
        ldaa    #>(START-1)
        psha
        ldaa    #<(START-1)
        psha
        jsr     LOADBC
        ldx     BREG
        jmp     0,X
        
;;;;;;;;;;

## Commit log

2016-03-15 Update assembly to asxxxx format Checkin trivial build script
2016-03-18 Add wiring description
2016-06-14 Fixed crash when reading non-ascii char from keyboard Fixed Modify command to allow skip (enter) and abort (esc) Added help menu More cleanups
    [demon.py]
2016-09-26 Fix crash with L command
    [demon.py]
2017-03-24 Change to newer formatted printing. tiny cleanups
2017-03-28 Fix for LTO Flash handshaking - requires rtscts=True
    [demon.py]
2017-04-04 demon: Remove windows-specific keyboard handling, fix C cmd for CP1610
    [demon.py, kbhit.py]
2017-04-05 demon: Return error if range is negative for D,W,F,S commands
    [demon.py]
2018-08-24 Add support to demon.py for 6502. Fix bug with some Z80 commands
    [demon.py]
2018-08-31 Add Intellivision Cart image
    [demondbg.cfg]
2020-01-14 Fix comments for bit90.asm
    [bit90.asm]
2021-05-19 Use Arduino builtin LED to indicate I2C traffic
2021-07-31 Rev A of Hardware
    [io_i2c-B_Cu.gbr, io_i2c-B_Fab.gbr, io_i2c-B_Mask.gbr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]
2021-07-31 Hardware Rev B WIP
    [io_i2c.kicad_pcb, io_i2c.sch]
2022-02-28 Add hardware Rev. C - new way of handling writing via reading to avoid sample time variation, also upgrade to KiCad 6
    [io_i2c.kicad_pcb, io_i2c.kicad_sch, io_i2c.sch]
2022-02-28 added parallel interface
    [io_i2c.kicad_sch]
2022-02-28 added pulldown for floating fet
    [io_i2c.kicad_sch]
2022-03-01 edited for rev C
    [io_i2c.kicad_pcb, io_i2c.kicad_sch]
2022-03-13 fixed layout a bit and a trace missing, generated gerbers
    [io_i2c-B_Cu.gbl, io_i2c-B_Fab.gbr, io_i2c-B_Mask.gbs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]
2022-03-14 gerber zip
2022-06-29 latest rev changing memory map, revD
    [io_i2c-B_Cu.gbl, io_i2c-B_Fab.gbr, io_i2c-B_Mask.gbs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]
2022-06-29 board edit for revD, not done yet
    [io_i2c.kicad_pcb]
2022-06-30 Lots to verify here
    [io_i2c-B_Cu.gbr, io_i2c-B_Fab.gbr, io_i2c-B_Mask.gbr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]
2022-06-30 revised schematic
2022-06-30 added diode for programming
    [io_i2c.kicad_sch]
2022-06-30 fixed pullup
    [io_i2c.kicad_sch]
2022-06-30 fix crossed wires
    [io_i2c.kicad_sch]
2022-07-07 Update Arduino code to support Hardware Rev. D
2022-07-07 Update 6502 target code to support Rev C and D boards
2022-07-09 Fix bug where IO reads/writes could be out of range
    [ref6502.asm, starshp1.asm]
2022-07-09 diode fix for decoding writes
    [io_i2c.kicad_sch]
2022-07-09 Make kicad happy
2022-07-10 Add some scope image captures of I2C traffic
2022-07-14 Fixup 6502 code from merge
    [ref6502.asm]
2022-07-14 Update 6502 assembler/listing settings
2022-07-14 Move ArduinoUno target under a directory
2022-07-14 Resync hardware with abzman branch
    [io_i2c-B_Cu.gbr, io_i2c-B_Fab.gbr, io_i2c-B_Mask.gbr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]
2022-07-14 Add a couple blank images for testing
2022-07-15 revD board
    [io_i2c.kicad_pcb]
2022-07-16 Add .gitignore for Kicad
2022-07-16 Remove C6, Updated warning label, new pdf
    [io_i2c.kicad_pcb, io_i2c.kicad_sch]
2022-07-16 Remove obsolete files
    [io_i2c.sch]
2022-07-16 New msg about shorter roms
    [io_i2c.kicad_sch]
2022-07-18 added silk regions, labeling, jumper for rom emulator mode
    [io_i2c.kicad_pcb, io_i2c.kicad_sch]
2022-07-23 Migrate library with 2716 symbol to Kicad 6 format
2022-07-23 fixed silk, locations, and jumper
    [io_i2c.kicad_pcb, io_i2c.kicad_sch]
2022-07-23 Update schematic symbols from pcb
    [io_i2c.kicad_sch]
2022-08-06 update to schematic only for potential additional positive chip select
    [io_i2c.kicad_sch]
2022-08-07 added layout change for extra CS mode
    [io_i2c.kicad_pcb, io_i2c.kicad_sch]
2022-08-09 changed some ref des-es to make jumper numbering more sane
    [io_i2c.kicad_pcb, io_i2c.kicad_sch]
2022-08-14 Extract the CPU type from the code, and pick the right assembler automatically
2022-08-17 Move LTOFlash binaries to new area
    [demondbg.cfg]
2022-08-20 gerbers and ERC DRC fixes
    [io_i2c-B_Cu.gbl, io_i2c-B_Fab.gbr, io_i2c-B_Mask.gbs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]
2022-08-23 First cut at et3400 target - untested
2022-08-23 Fix a possible bug in the 6502 main code, and fix formatting
    [6502_main.asm]
2022-10-29 added pull up and silk changes
    [io_i2c.kicad_pcb, io_i2c.kicad_sch]
2022-10-29 moved to rev E and updated
    [io_i2c.kicad_pcb, io_i2c.kicad_sch]
2022-11-05 rev e complete overhaul of decoding logic, includes one of 2 possible glitch eliminator circuits
    [io_i2c.kicad_sch]
2022-11-09 added CS multiplexer for use with rev E board, finished rev E layout
    [chip select multiplexer.kicad_pcb, chip select multiplexer.kicad_sch, io_i2c.kicad_pcb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]
2023-01-06 added gerbers
    [chip select multiplexer-B_Cu.gbl, chip select multiplexer-B_Mask.gbs, chip select multiplexer-B_Paste.gbp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]
2024-07-28 added mousebites adapter
    [DIP28 to TC53257F.kicad_pcb, DIP28 to TC53257F.kicad_sch]
2026-02-11 changes from ordering the latest pcbs
    [chip select multiplexer.kicad_pcb, io_i2c.kicad_pcb]
2026-10-31 added revisons to the code that work with board E and a resistor to the board that lets the code disable the i2c portion for eeprom programming
